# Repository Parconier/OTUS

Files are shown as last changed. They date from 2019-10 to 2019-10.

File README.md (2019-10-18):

# OTUS: 3D Printed Robotics Kit by Parconier 

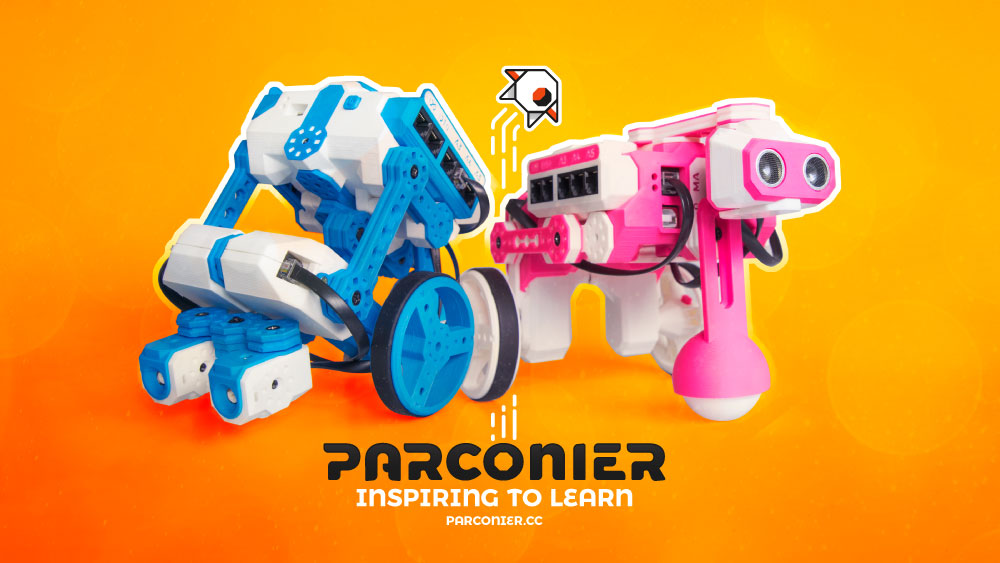
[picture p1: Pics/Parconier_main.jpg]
OTUS


[Click here to purchase one from the Abierto shop](https://www.abierto.cc/shop/#tags=10849|10852 "abierto.cc")

# Files in this repository

.STL - This files are for 3D printing, if you want to edit any of them, feel free to use the .STEP file.
.STEP - This files contains every pattern in a generic 3D format that you can easily edit.

# Name format

name of the piece "\_" suggestion of color of neutral "\_" ammount per kit "\- v" version of the file

Example:
Patternx2\_color\_x6 \-  v1.0

# License

Copyright CERN 2013. 

This documentation describes Open Hardware and is licensed under the CERN OHL v. 1.2. This means that you are free to use, reproduce, sell or modify our designs in any way you see fit, as long as you retain this same license for your projects using our work. For those wanting to use our hardware designs and/or software packages, we require you:

Label the product as a clone. It must be clear that it is not a product from our factory.
Note that "OTUS is a registered trademark of Parconier".
Host your own copy of the source files on your own server or similar, even if they are unmodified. Do not just point to our existing source.

You may redistribute and modify this documentation under the terms of the CERN OHL v.1.2. (http://ohwr.org/cernohl). This documentation is distributed WITHOUT ANY EXPRESS OR IMPLIED WARRANTY, INCLUDING OF MERCHANTABILITY, SATISFACTORY QUALITY AND FITNESS FOR A PARTICULAR PURPOSE. Please see the CERN OHL v.1.2 for applicable conditions.

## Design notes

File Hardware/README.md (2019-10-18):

# PCB files for the OTUS 3D Printed Robotics Kit  

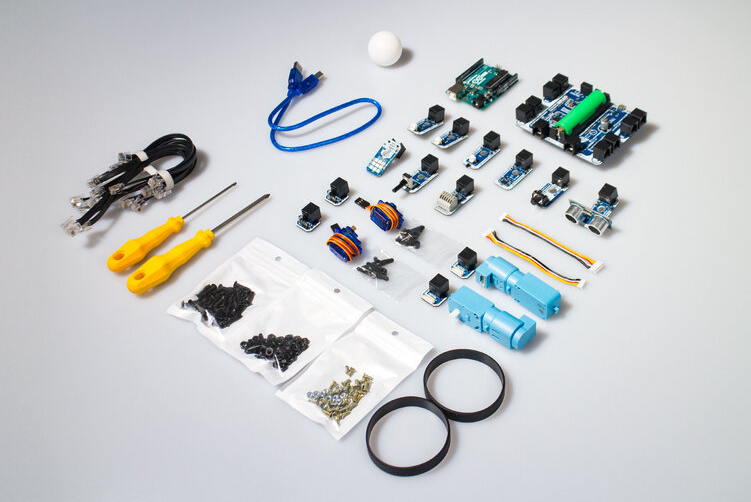
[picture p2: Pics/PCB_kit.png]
OTUS PCB kit


[Click here to purchase OTUS PCB boards from the Abierto shop](https://www.abierto.cc/shop/product/67049/otus-electronica/ "abierto.cc")

 Format is EagleCAD for Schematic and board layout.

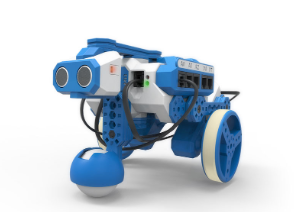
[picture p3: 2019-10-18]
Pics/OTUS.png

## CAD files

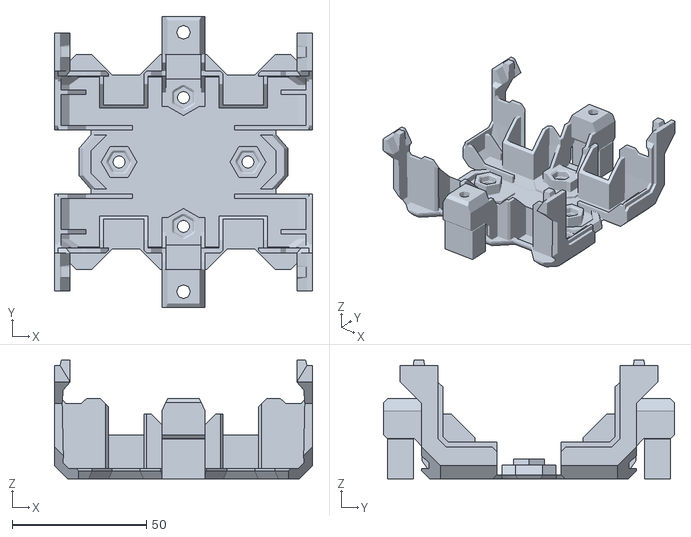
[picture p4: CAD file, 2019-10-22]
Construction System/Enclosures - v0.2/Interface - v0.2/interface_mainA_neutral_x1_v0.2.stl
96.2 x 108.4 x 44.3

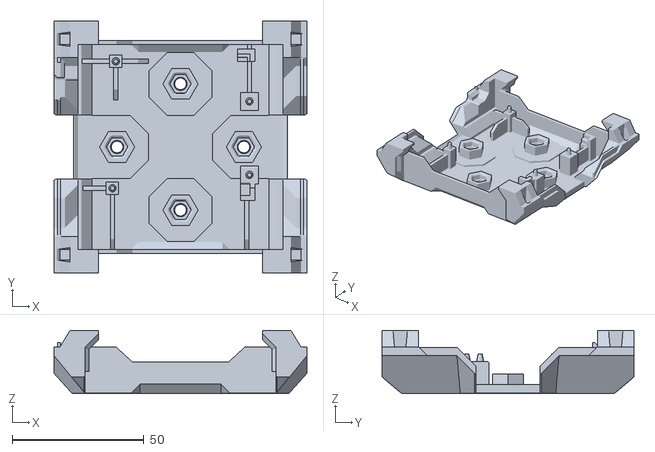
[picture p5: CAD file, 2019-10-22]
Construction System/Enclosures - v0.2/Interface - v0.2/interface_mainB_neutral_x1_v0.2.stl
96.2 x 96.0 x 24.0

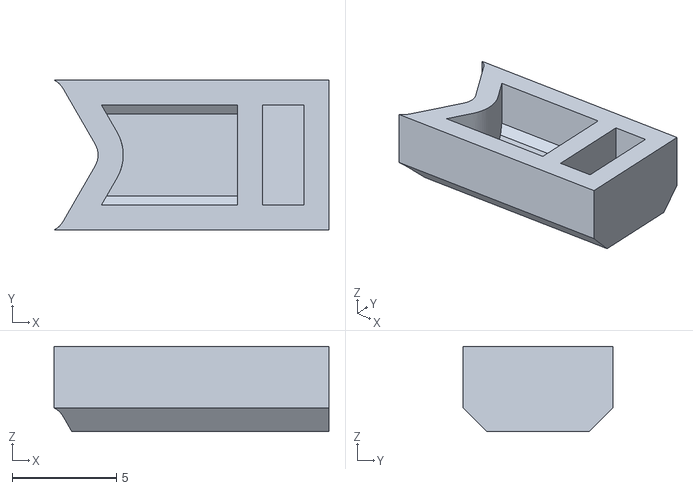
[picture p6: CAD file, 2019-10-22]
Construction System/Enclosures - v0.2/Actuators/Motor - v0.1/wheel_lock_neutral_x2_v0.1.stl
13.2 x 7.20 x 4.10

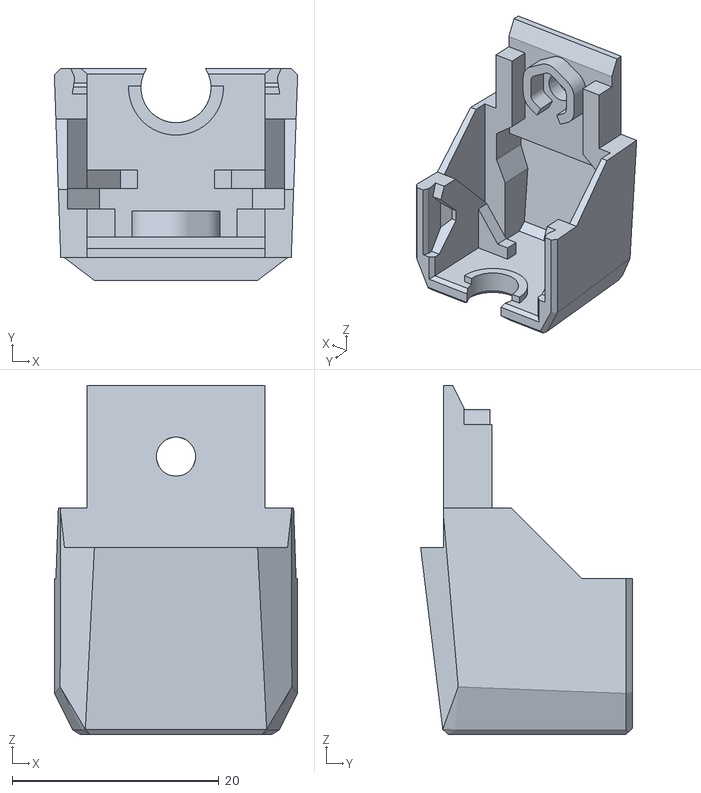
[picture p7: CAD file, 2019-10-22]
Construction System/Enclosures - v0.2/Actuators/Potenciometer - v0.2/pote_female_color_x1_v0.2.stl
23.6 x 20.5 x 33.8

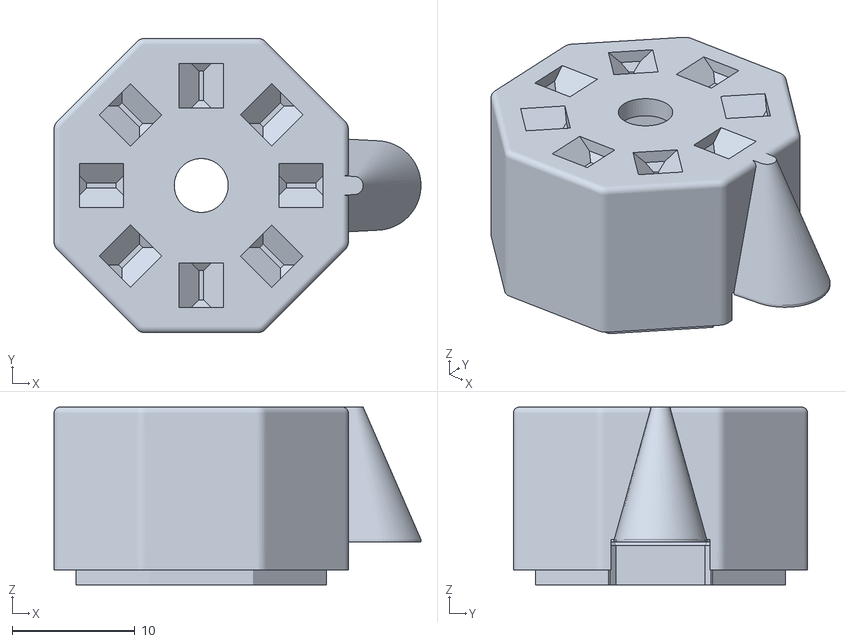
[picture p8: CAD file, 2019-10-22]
Construction System/Enclosures - v0.2/Actuators/Servomotor - v0.1/servo_headB_neutral_x2_v0.1.stl
29.9 x 24.0 x 14.5

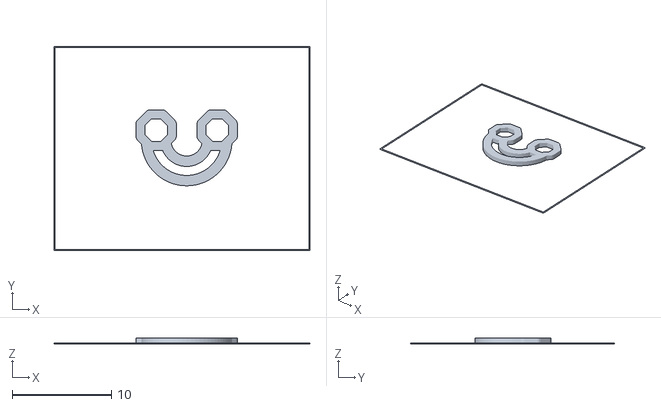
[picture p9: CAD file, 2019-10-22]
Construction System/Enclosures - v0.2/Others/Adapter - v0.2/adapter_female_neutral_x1_v0.2.stl
25.8 x 20.5 x 0.6

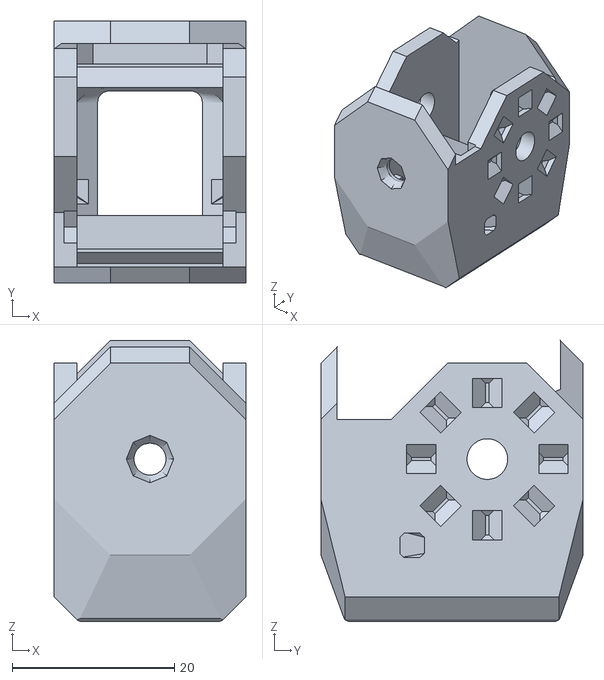
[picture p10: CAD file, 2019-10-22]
Construction System/Enclosures - v0.2/Sensors/Button_Sensor - v0.2/button_closure_neutral_x1_v0.2.stl
23.6 x 32.3 x 34.6

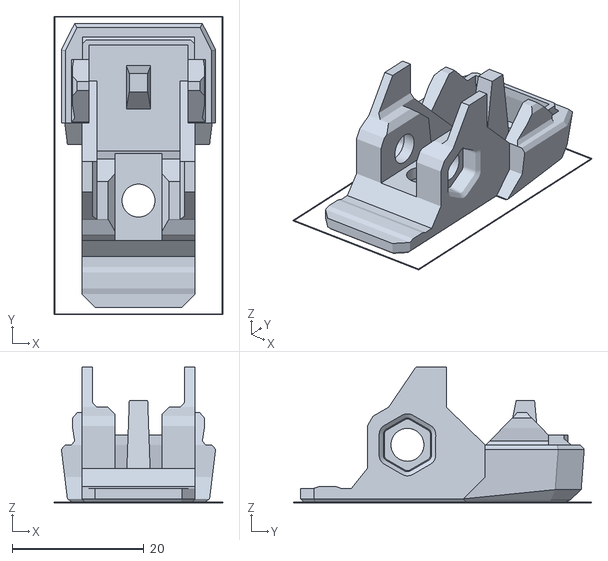
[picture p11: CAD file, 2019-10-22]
Construction System/Enclosures - v0.2/Sensors/Contrast_Sensor - v0.2/contrast_male_color_x2_v0.2.stl
25.6 x 45.3 x 20.6

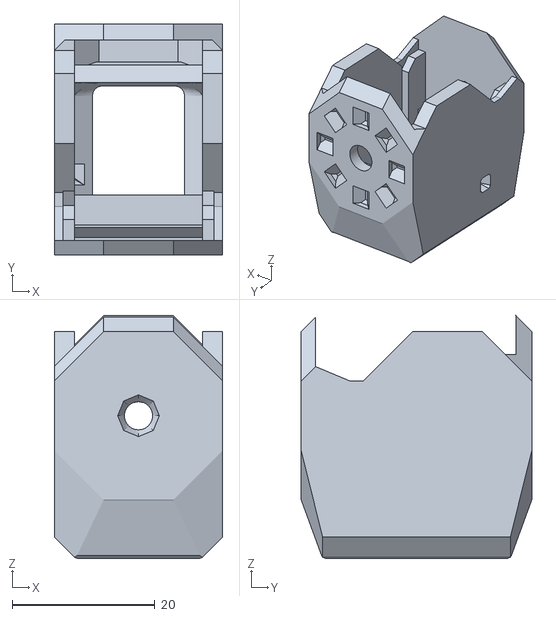
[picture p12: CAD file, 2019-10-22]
Construction System/Enclosures - v0.2/Sensors/Distance_Sensor - v0.2/distance_closure_neutral_x1_v0.2.stl
23.6 x 32.3 x 34.0

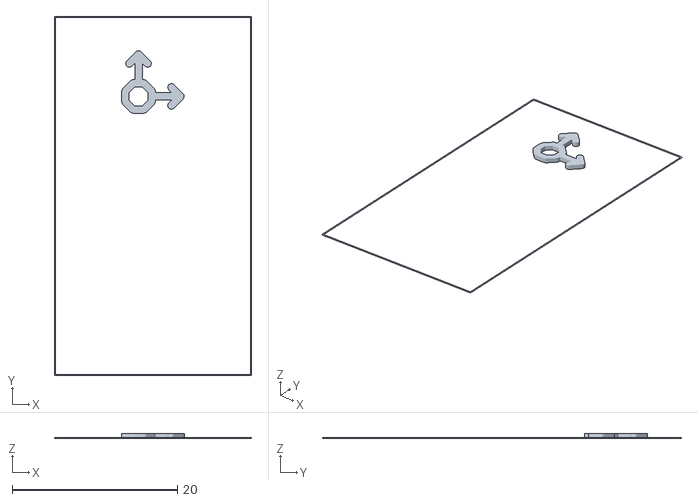
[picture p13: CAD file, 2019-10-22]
Construction System/Enclosures - v0.2/Sensors/IMU_Sensor - v0.2/IMU_male_neutral_x1_v0.2.stl
23.8 x 43.5 x 0.6

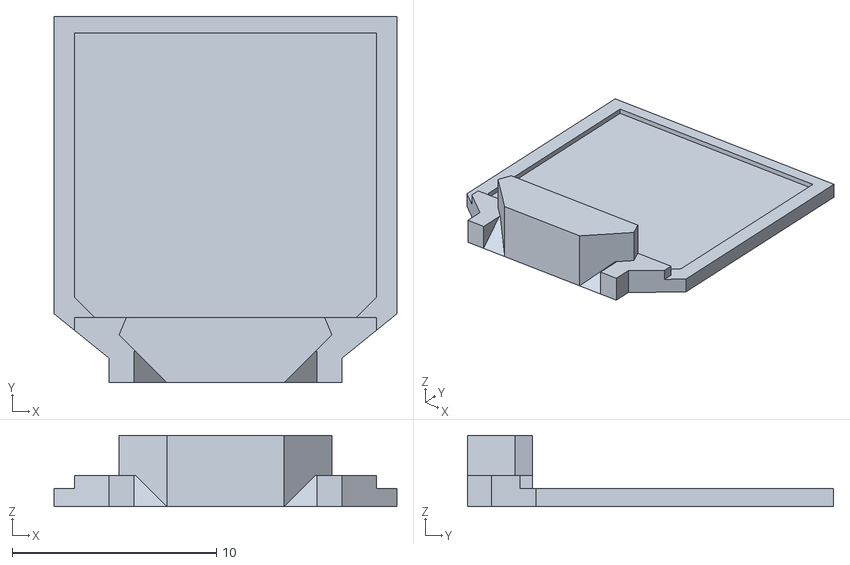
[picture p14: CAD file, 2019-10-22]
Construction System/Enclosures - v0.2/Sensors/LED_Matrix_3x3 - v0.2/LEDM3x3_cover_neutral_x1_v0.2.stl
16.8 x 17.9 x 3.49

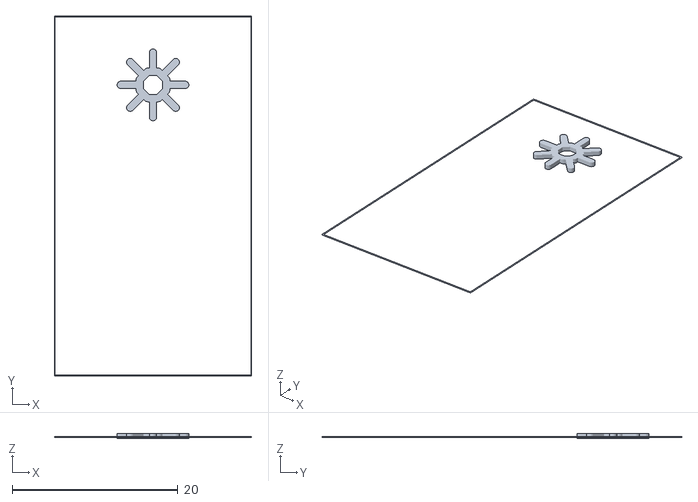
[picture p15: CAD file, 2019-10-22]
Construction System/Enclosures - v0.2/Sensors/Light_Sensor - v0.2/light_male_neutral_x1_v0.2.stl
23.8 x 43.5 x 0.6

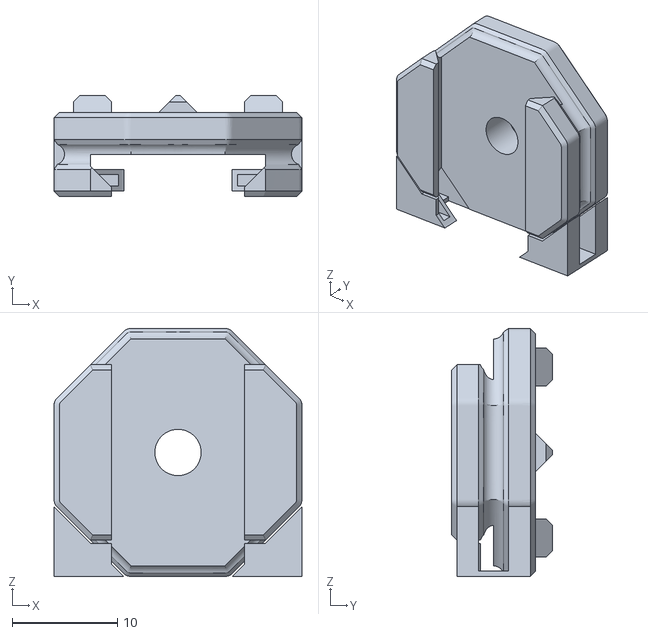
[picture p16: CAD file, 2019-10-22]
Construction System/Others - v0.2/Omni_wheel - v0.2/Omni_wheel_slider_neutral_x1_v02.stl
23.6 x 9.60 x 23.6

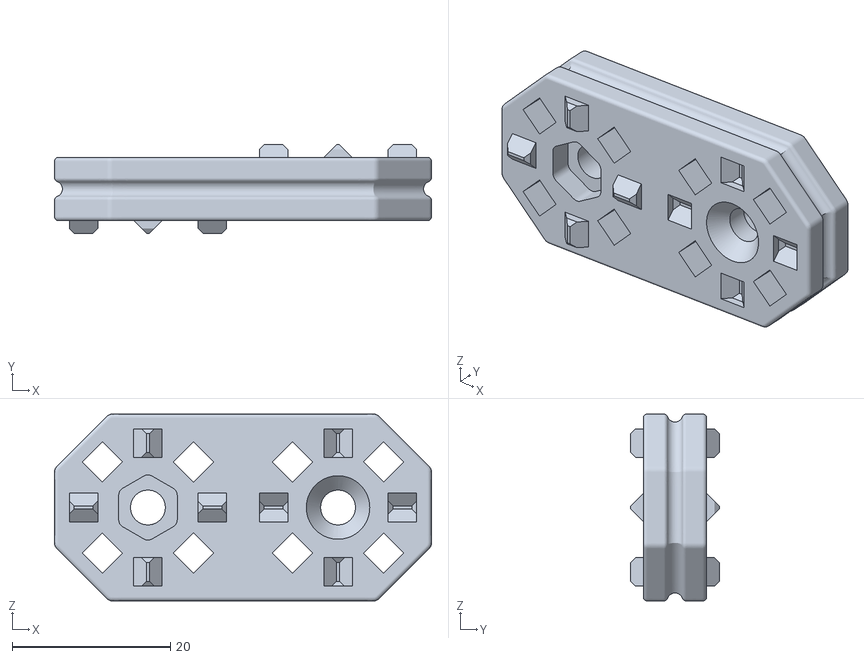
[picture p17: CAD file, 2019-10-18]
Construction System/Patterns - v0.2/Inversor_color_x3 - v0.2.stl
47.6 x 11.2 x 23.6

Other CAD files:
Construction System/Enclosures - v0.2/Actuators/Motor - v0.1/motor_closure1p_color_x2_v0.1.stl
Construction System/Enclosures - v0.2/Actuators/Potenciometer - v0.2/pote_knob_neutral_x1_v0.2.stl
Construction System/Enclosures - v0.2/Actuators/Servomotor - v0.1/servo_closure_neutral_x2_v0.1.stl
Construction System/Enclosures - v0.2/Interface - v0.2/interface_onoff_neutral_x1_v0.2.stl
Construction System/Enclosures - v0.2/Actuators/Motor - v0.1/motor_axis_color_x2_v0.1.stl
Construction System/Enclosures - v0.2/Actuators/Motor - v0.1/motor_closure2p_color_x2_v0.1.stl
Construction System/Enclosures - v0.2/Actuators/Motor - v0.1/motor_female_neutral_x2_v0.1.stl
Construction System/Enclosures - v0.2/Actuators/Motor - v0.1/motor_male_neutral_x2_v0.1.stl
Construction System/Enclosures - v0.2/Actuators/Motor - v0.1/wheel_color_x2_v0.1.stl
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

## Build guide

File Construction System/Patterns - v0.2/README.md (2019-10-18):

## Introduction

Here you will find all the different patterns that you can use or print.
The base pattern is a 24 mm octagon, pretty much everything derives from it, so if you would like to design something, this is the fundamental piece.

## Files
.STL - This files are for 3D printing the, if you want to edit any of them, feel free to use the .STEP file.
.STEP - This files contains every pattern in a generic 3D format that you can easily edit.

## Name format
name of the piece "\_" suggestion of color of neutral "\_" ammount per kit "\- v" version of the file

## Example:
Patternx2_color_x6 -  v1.0

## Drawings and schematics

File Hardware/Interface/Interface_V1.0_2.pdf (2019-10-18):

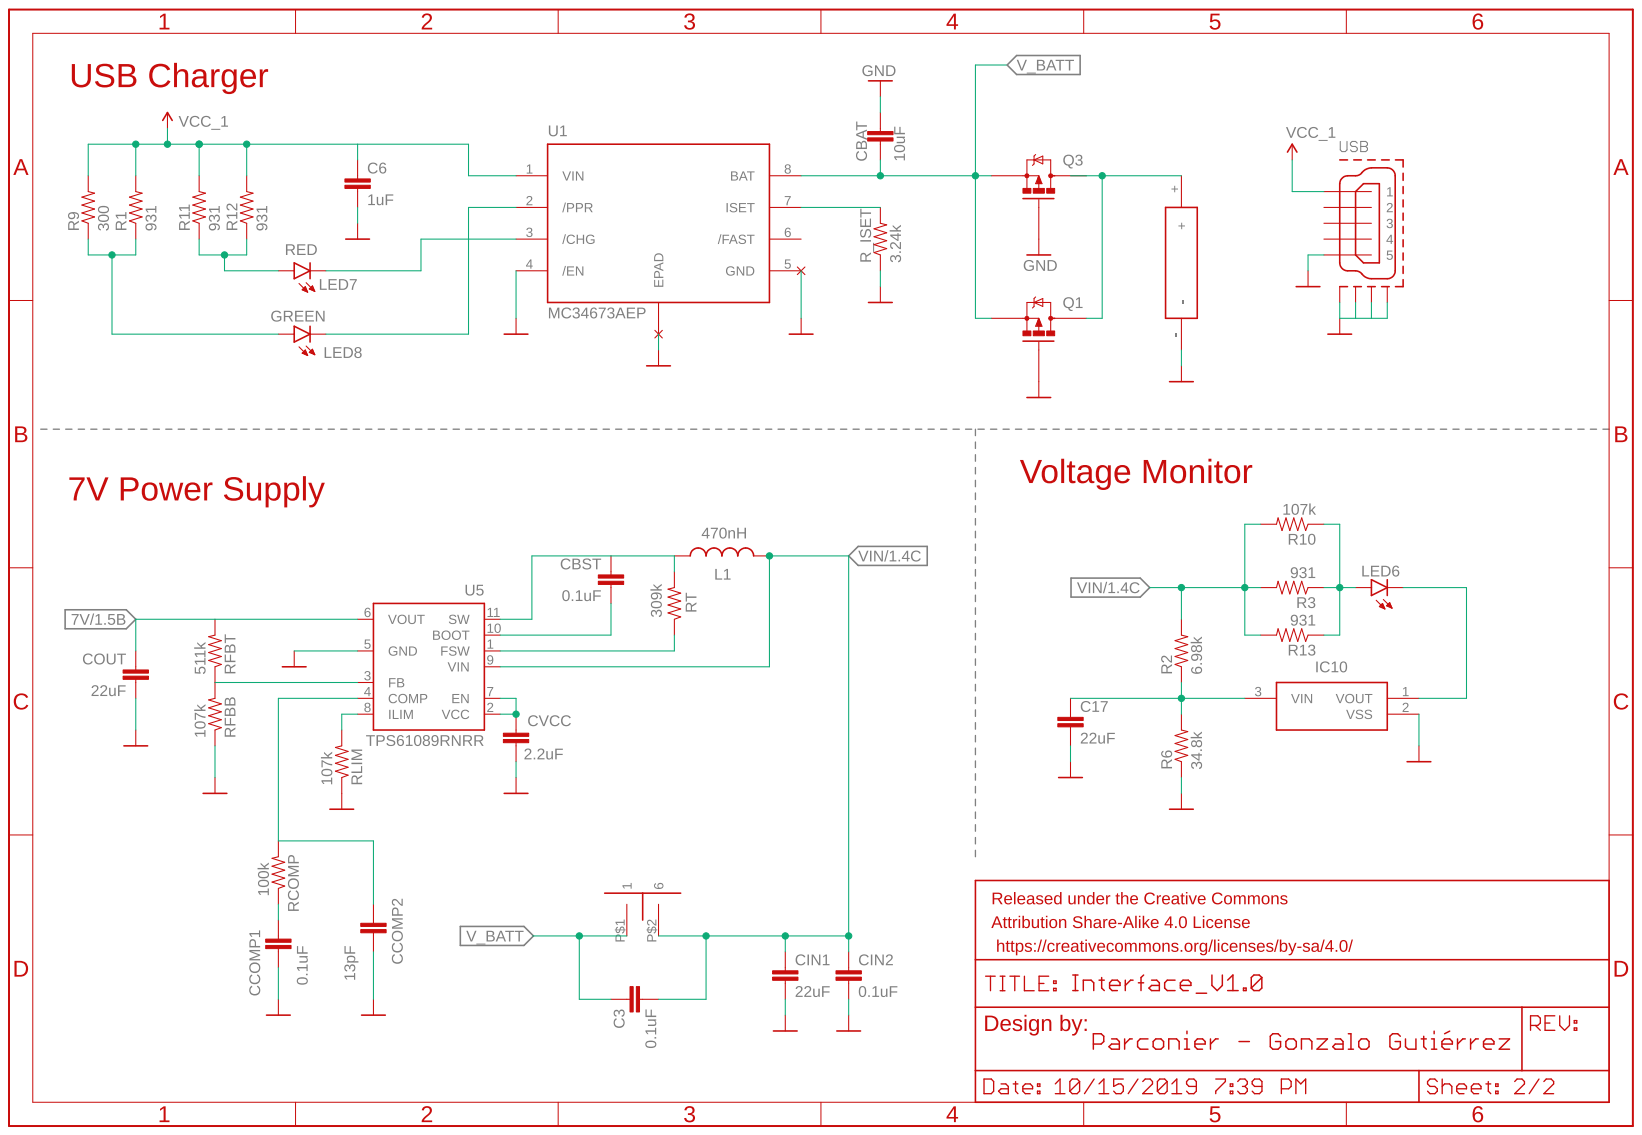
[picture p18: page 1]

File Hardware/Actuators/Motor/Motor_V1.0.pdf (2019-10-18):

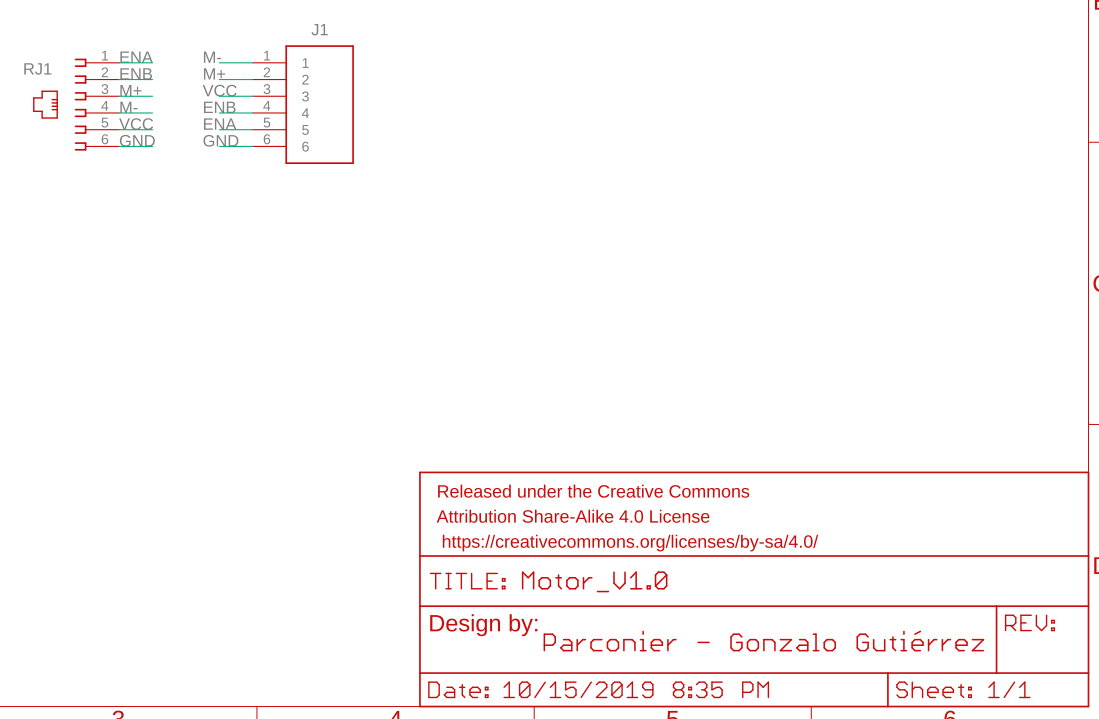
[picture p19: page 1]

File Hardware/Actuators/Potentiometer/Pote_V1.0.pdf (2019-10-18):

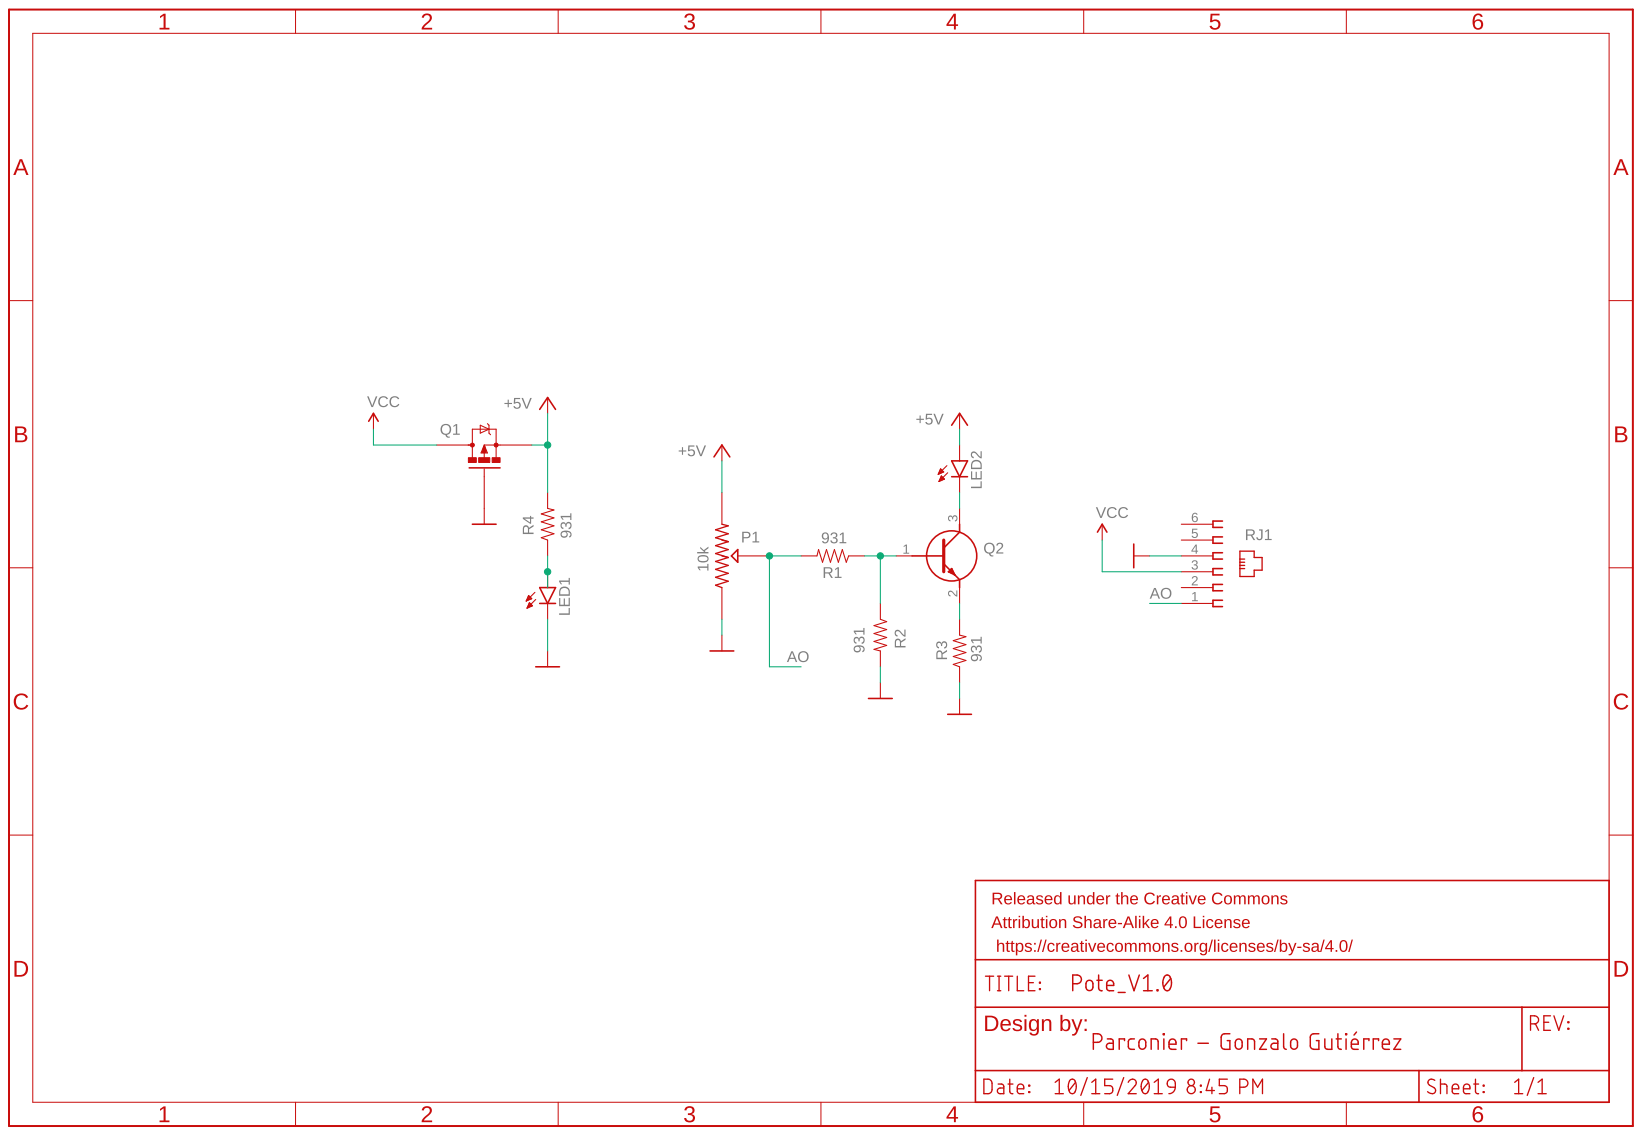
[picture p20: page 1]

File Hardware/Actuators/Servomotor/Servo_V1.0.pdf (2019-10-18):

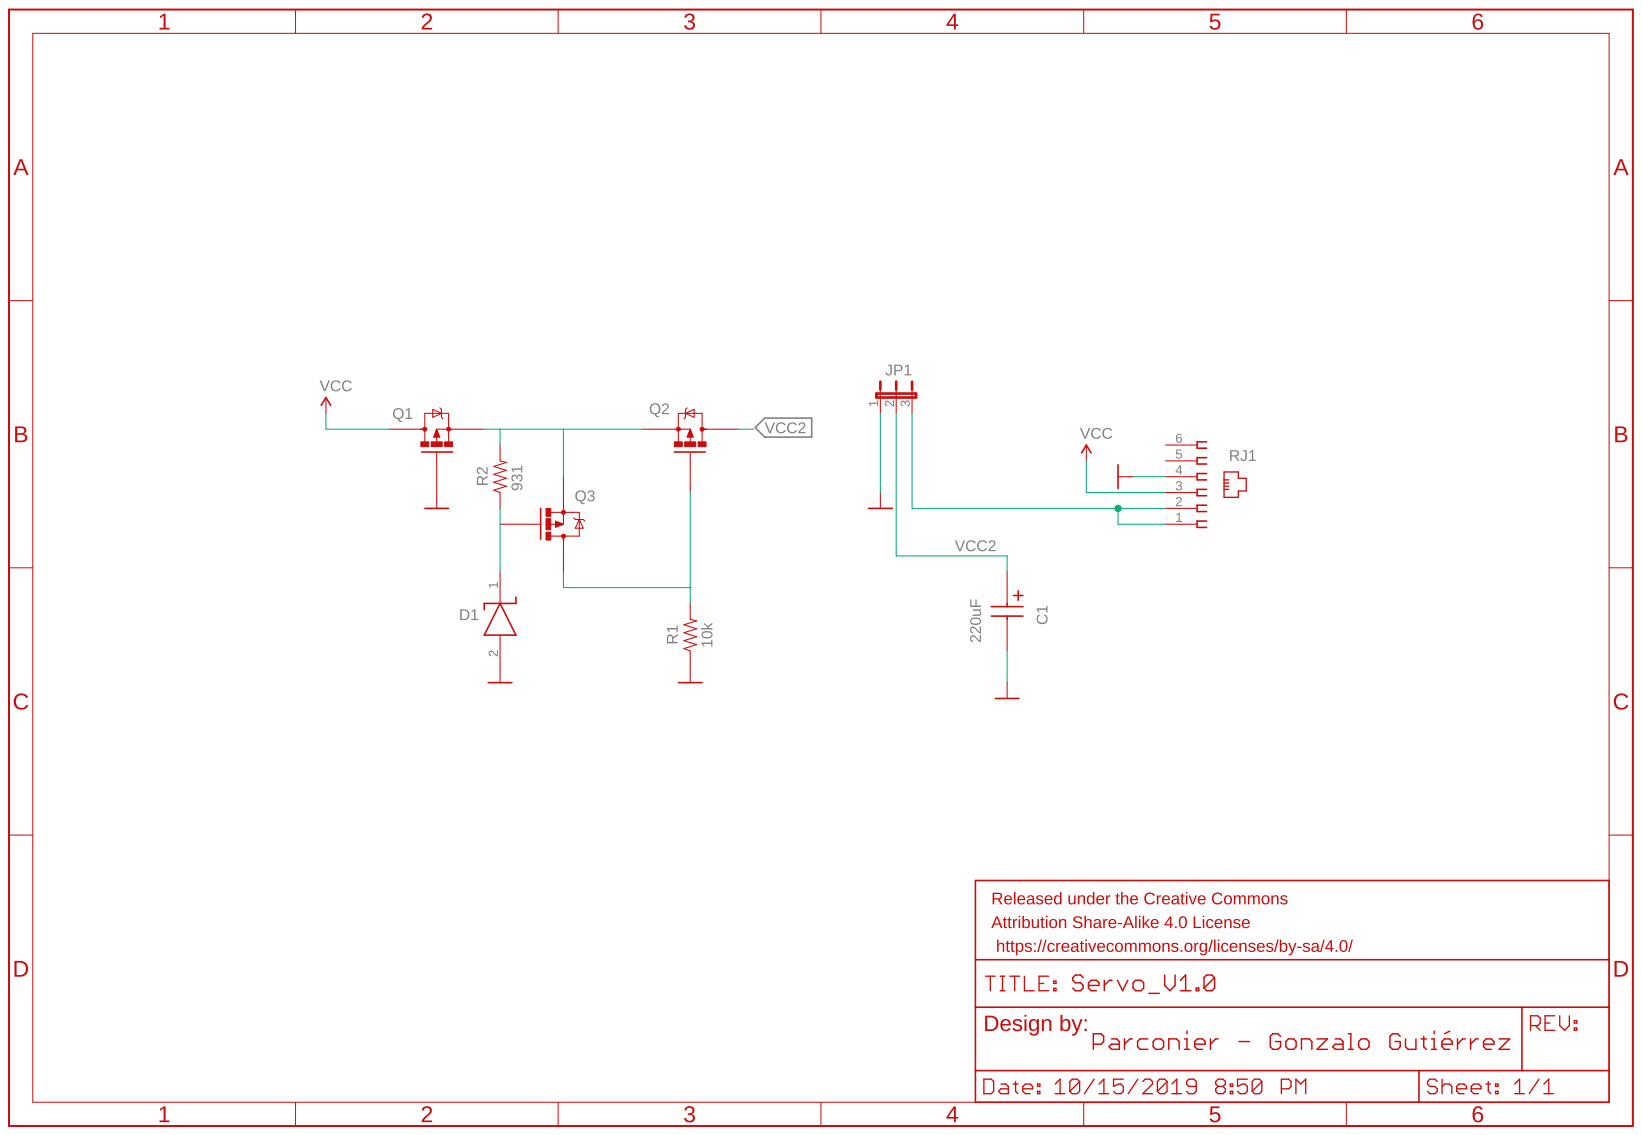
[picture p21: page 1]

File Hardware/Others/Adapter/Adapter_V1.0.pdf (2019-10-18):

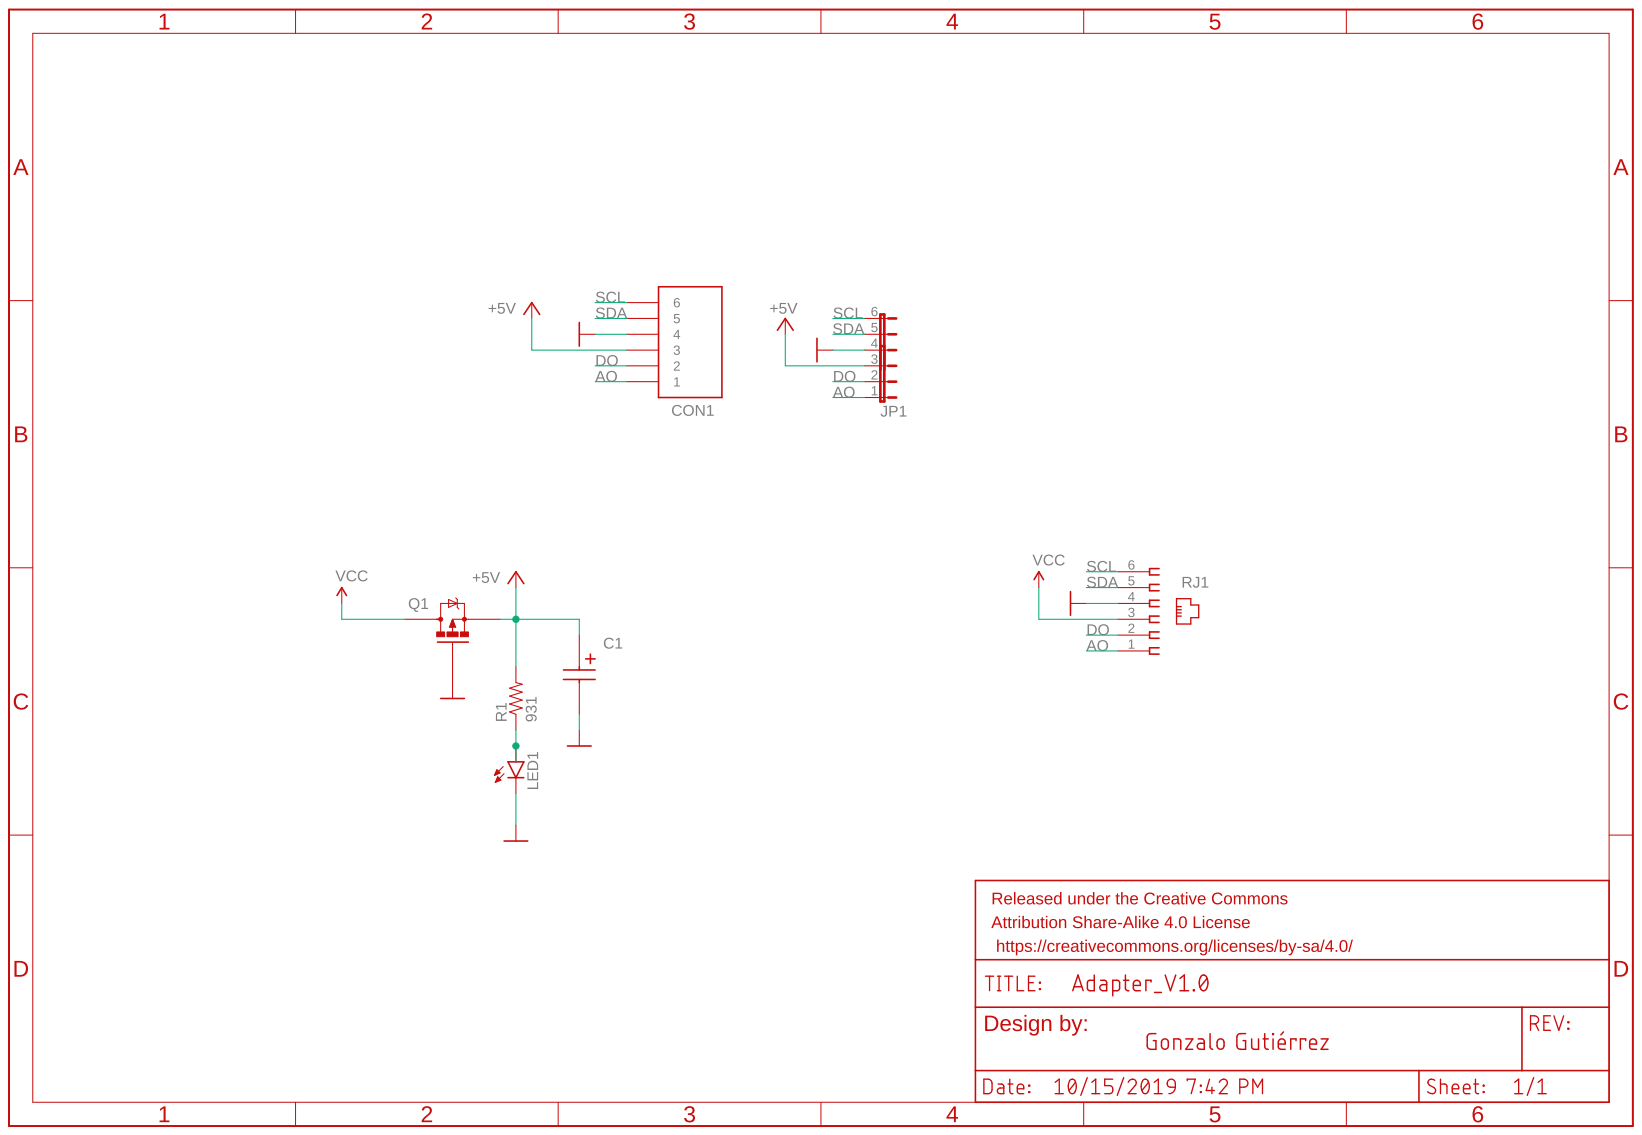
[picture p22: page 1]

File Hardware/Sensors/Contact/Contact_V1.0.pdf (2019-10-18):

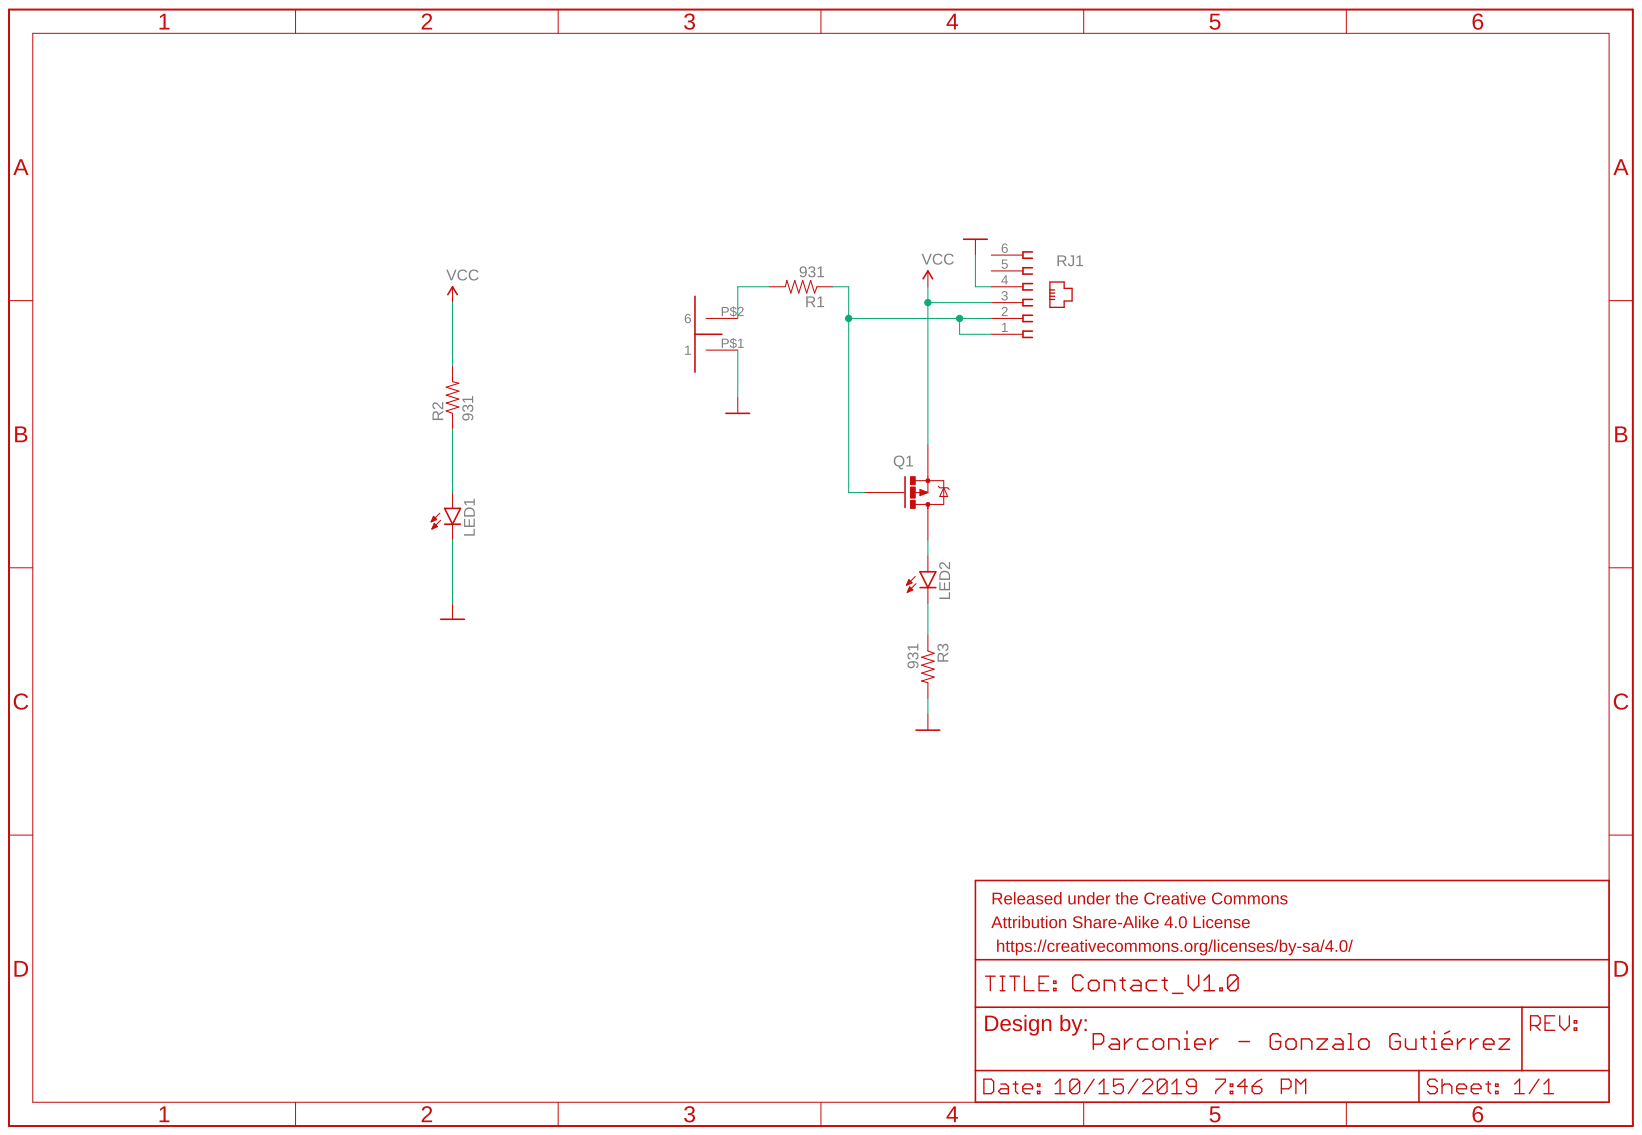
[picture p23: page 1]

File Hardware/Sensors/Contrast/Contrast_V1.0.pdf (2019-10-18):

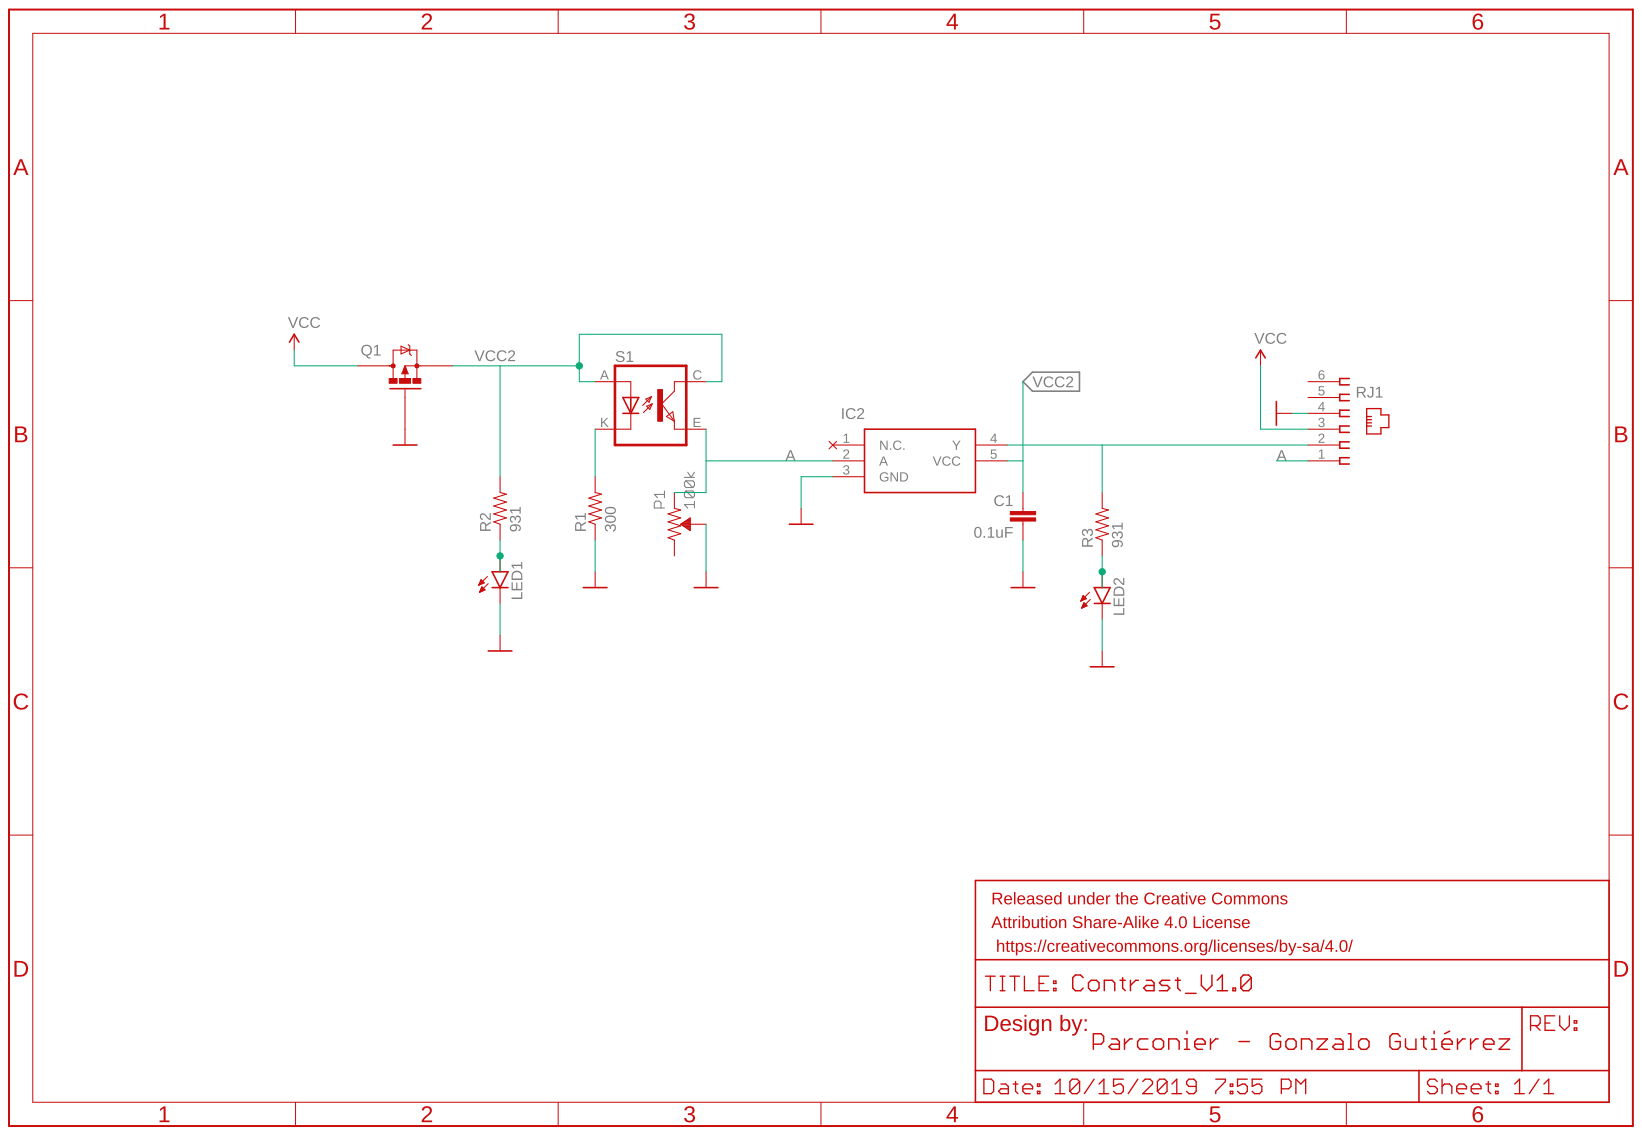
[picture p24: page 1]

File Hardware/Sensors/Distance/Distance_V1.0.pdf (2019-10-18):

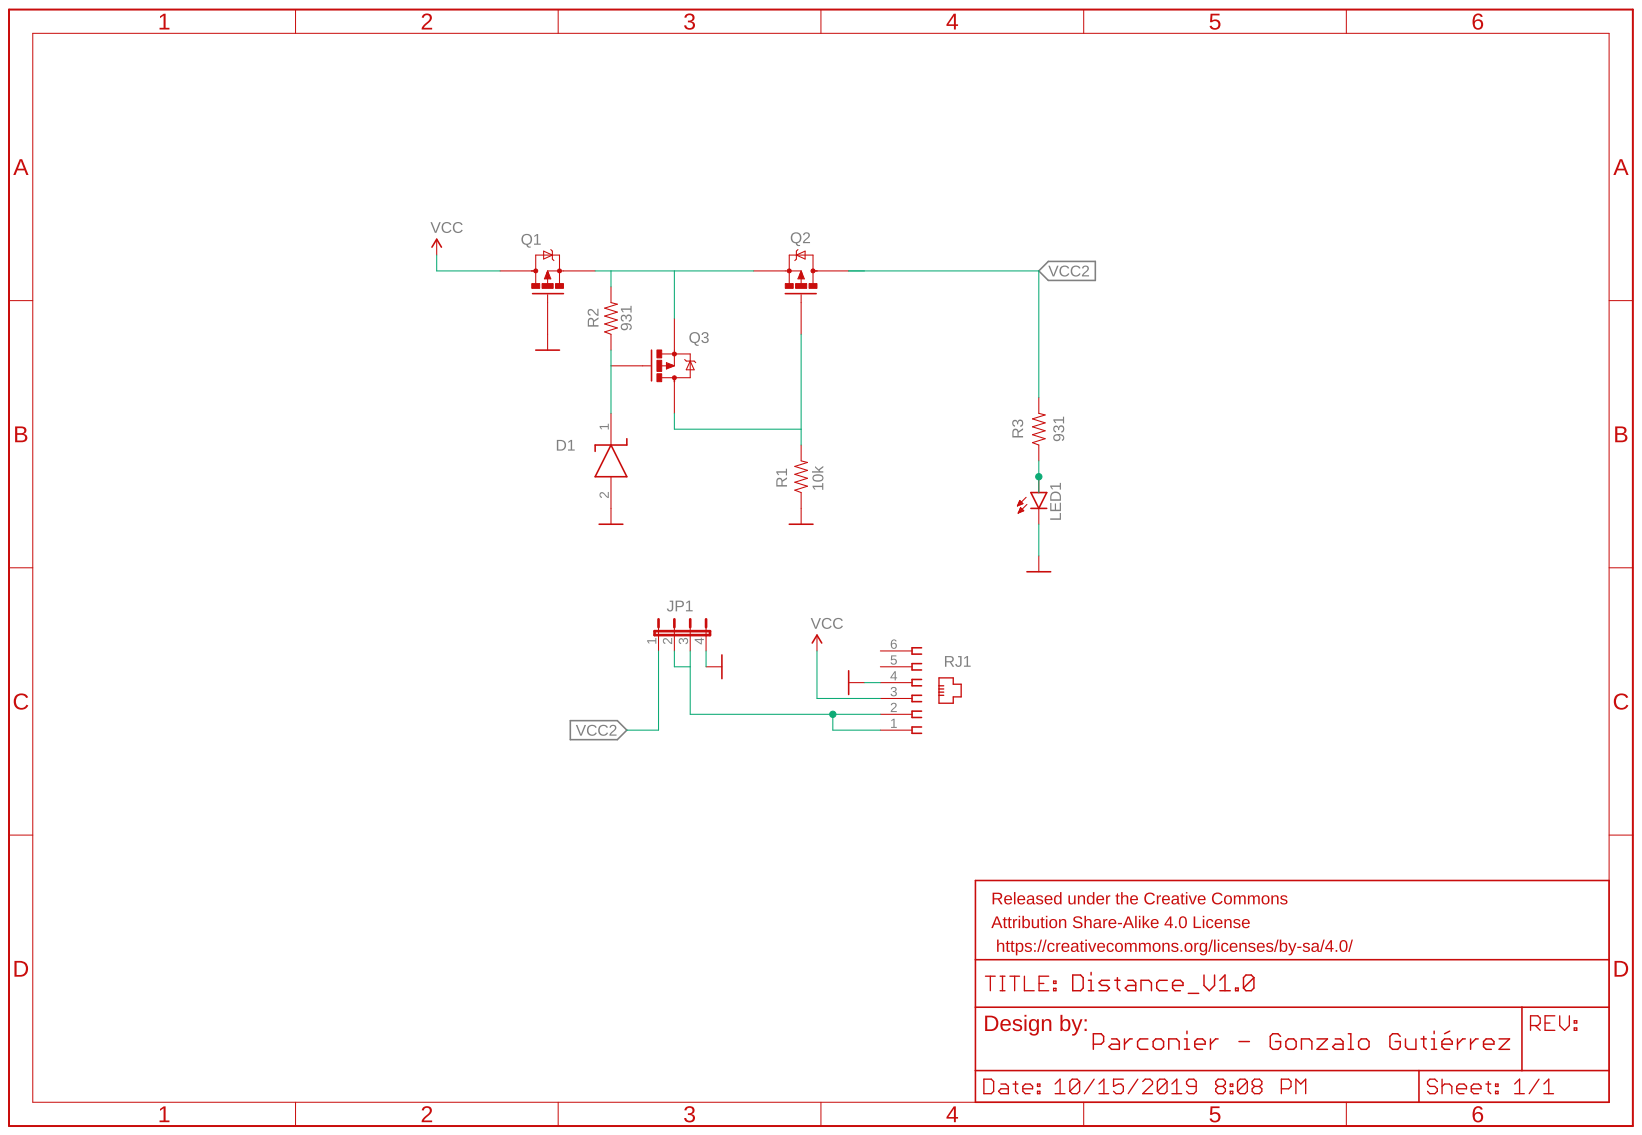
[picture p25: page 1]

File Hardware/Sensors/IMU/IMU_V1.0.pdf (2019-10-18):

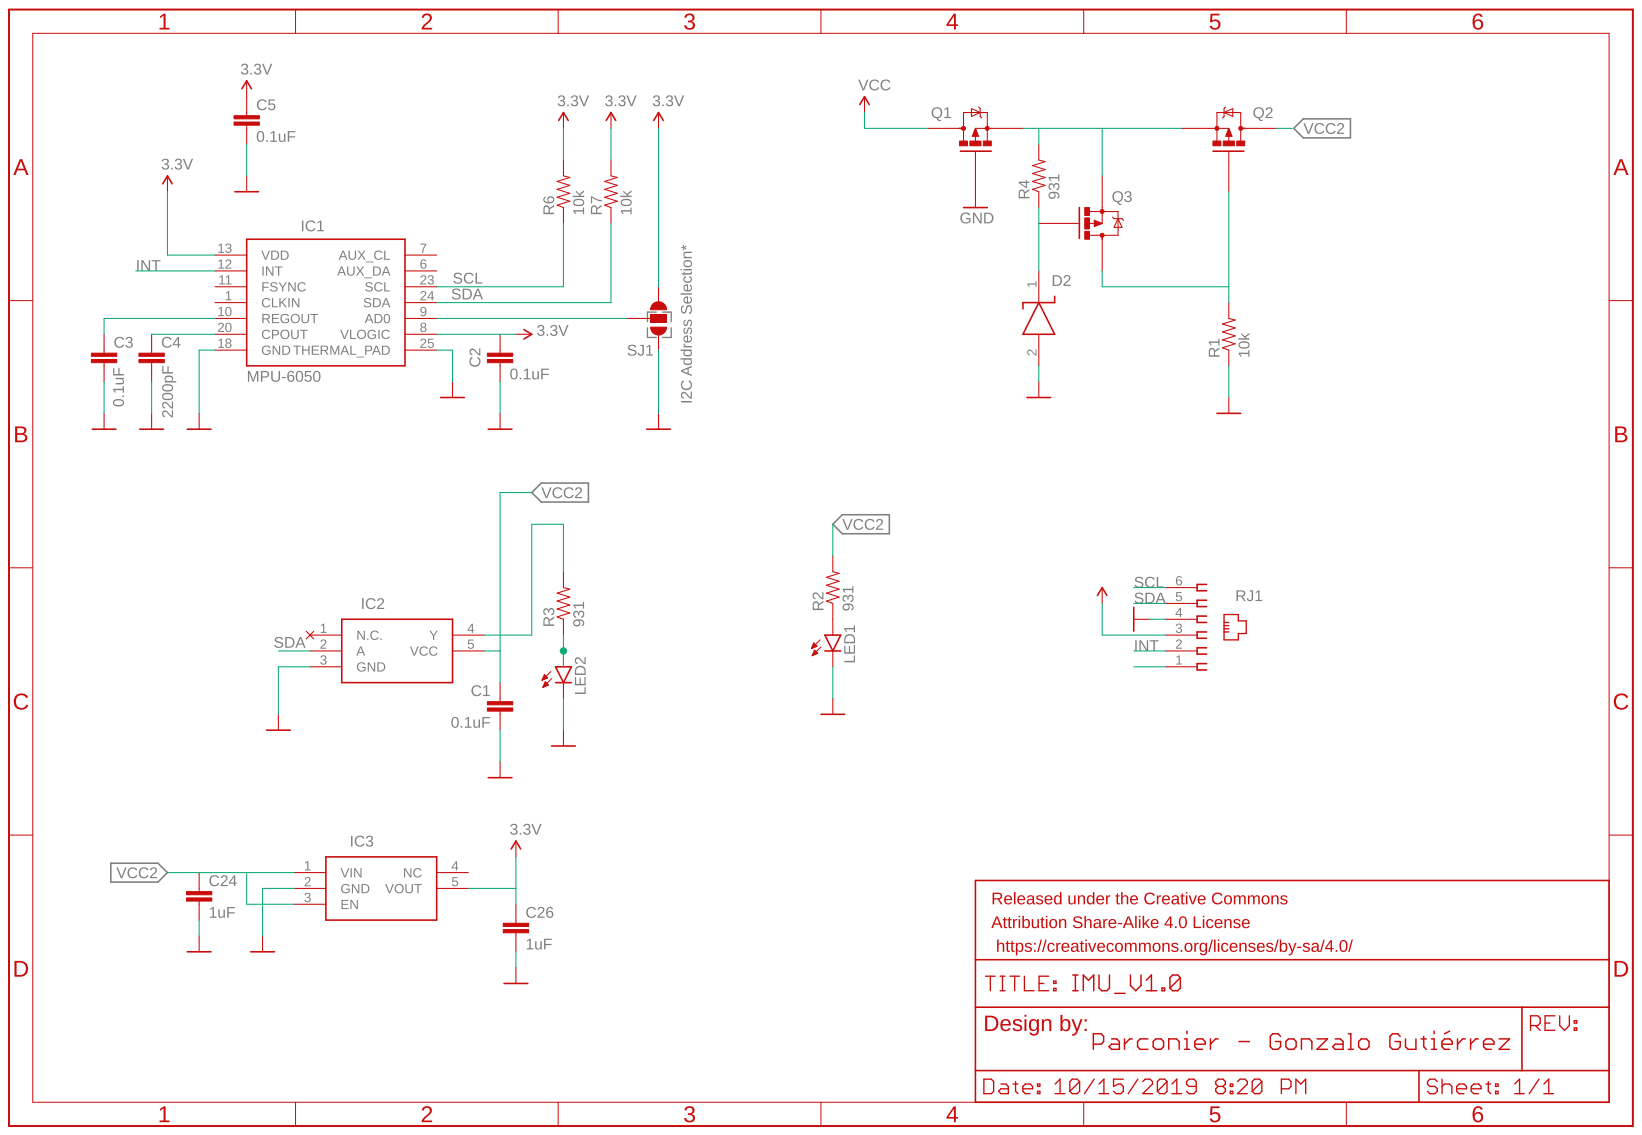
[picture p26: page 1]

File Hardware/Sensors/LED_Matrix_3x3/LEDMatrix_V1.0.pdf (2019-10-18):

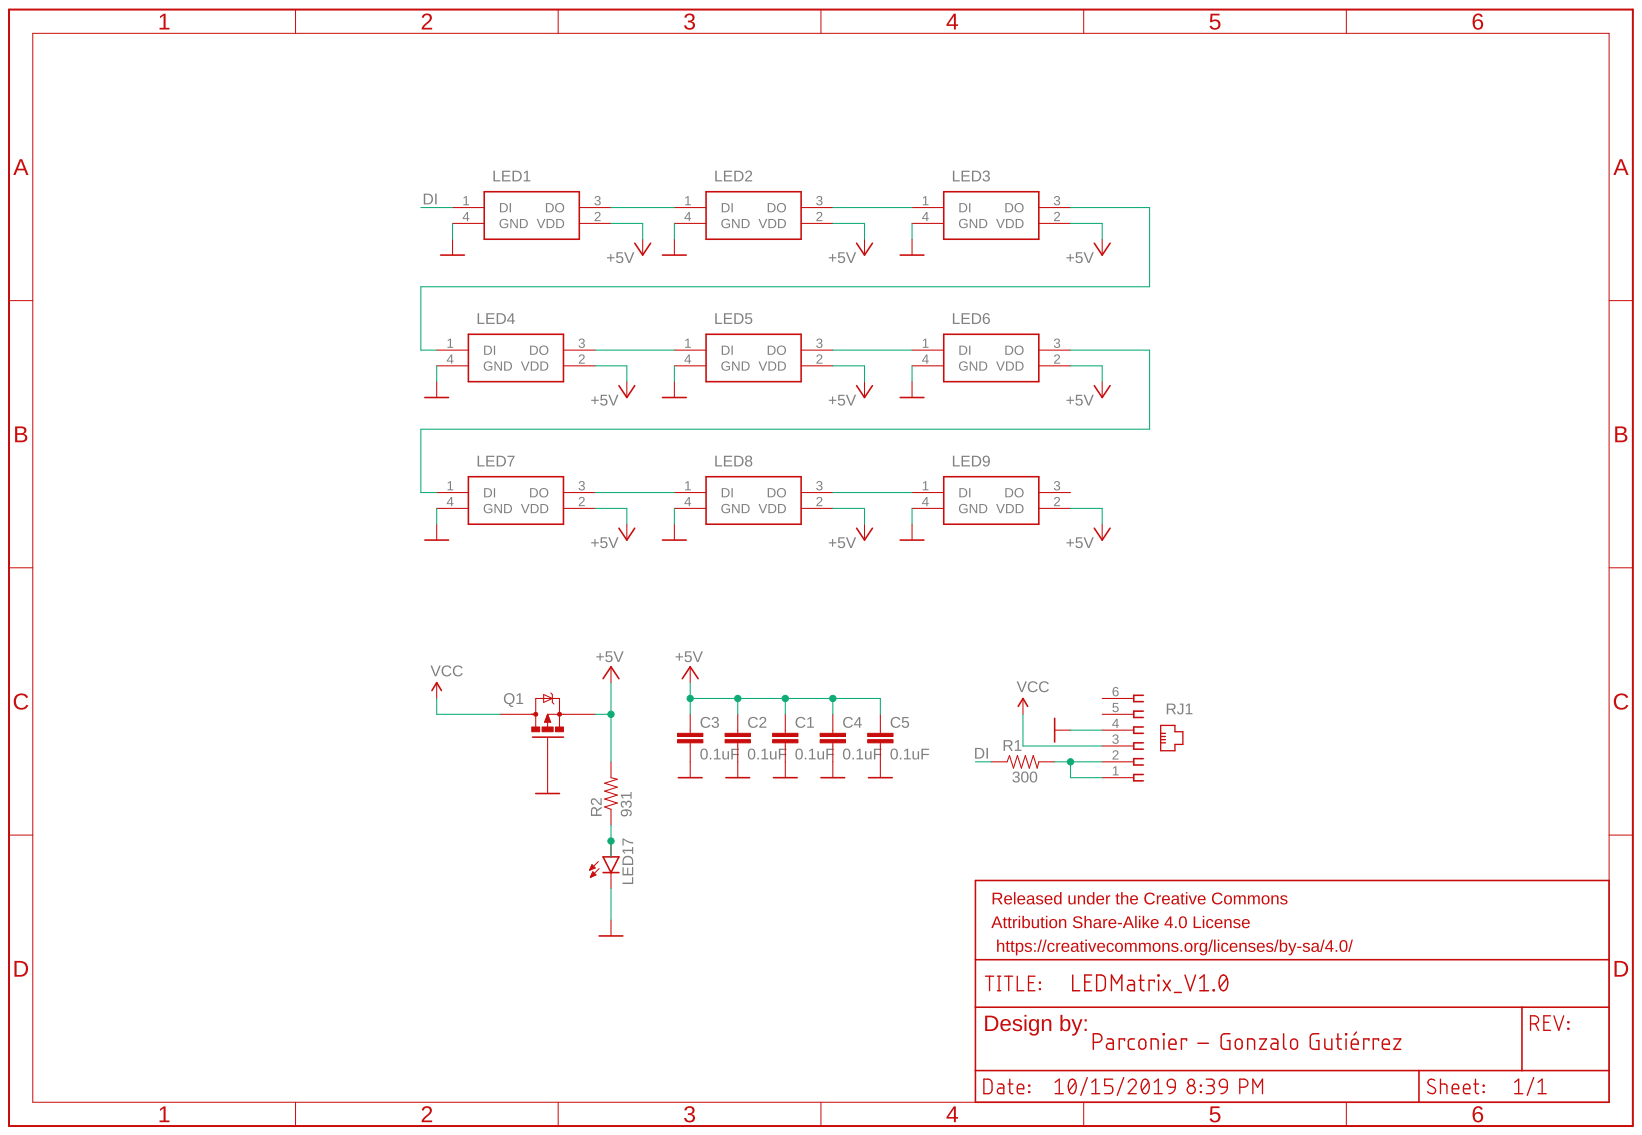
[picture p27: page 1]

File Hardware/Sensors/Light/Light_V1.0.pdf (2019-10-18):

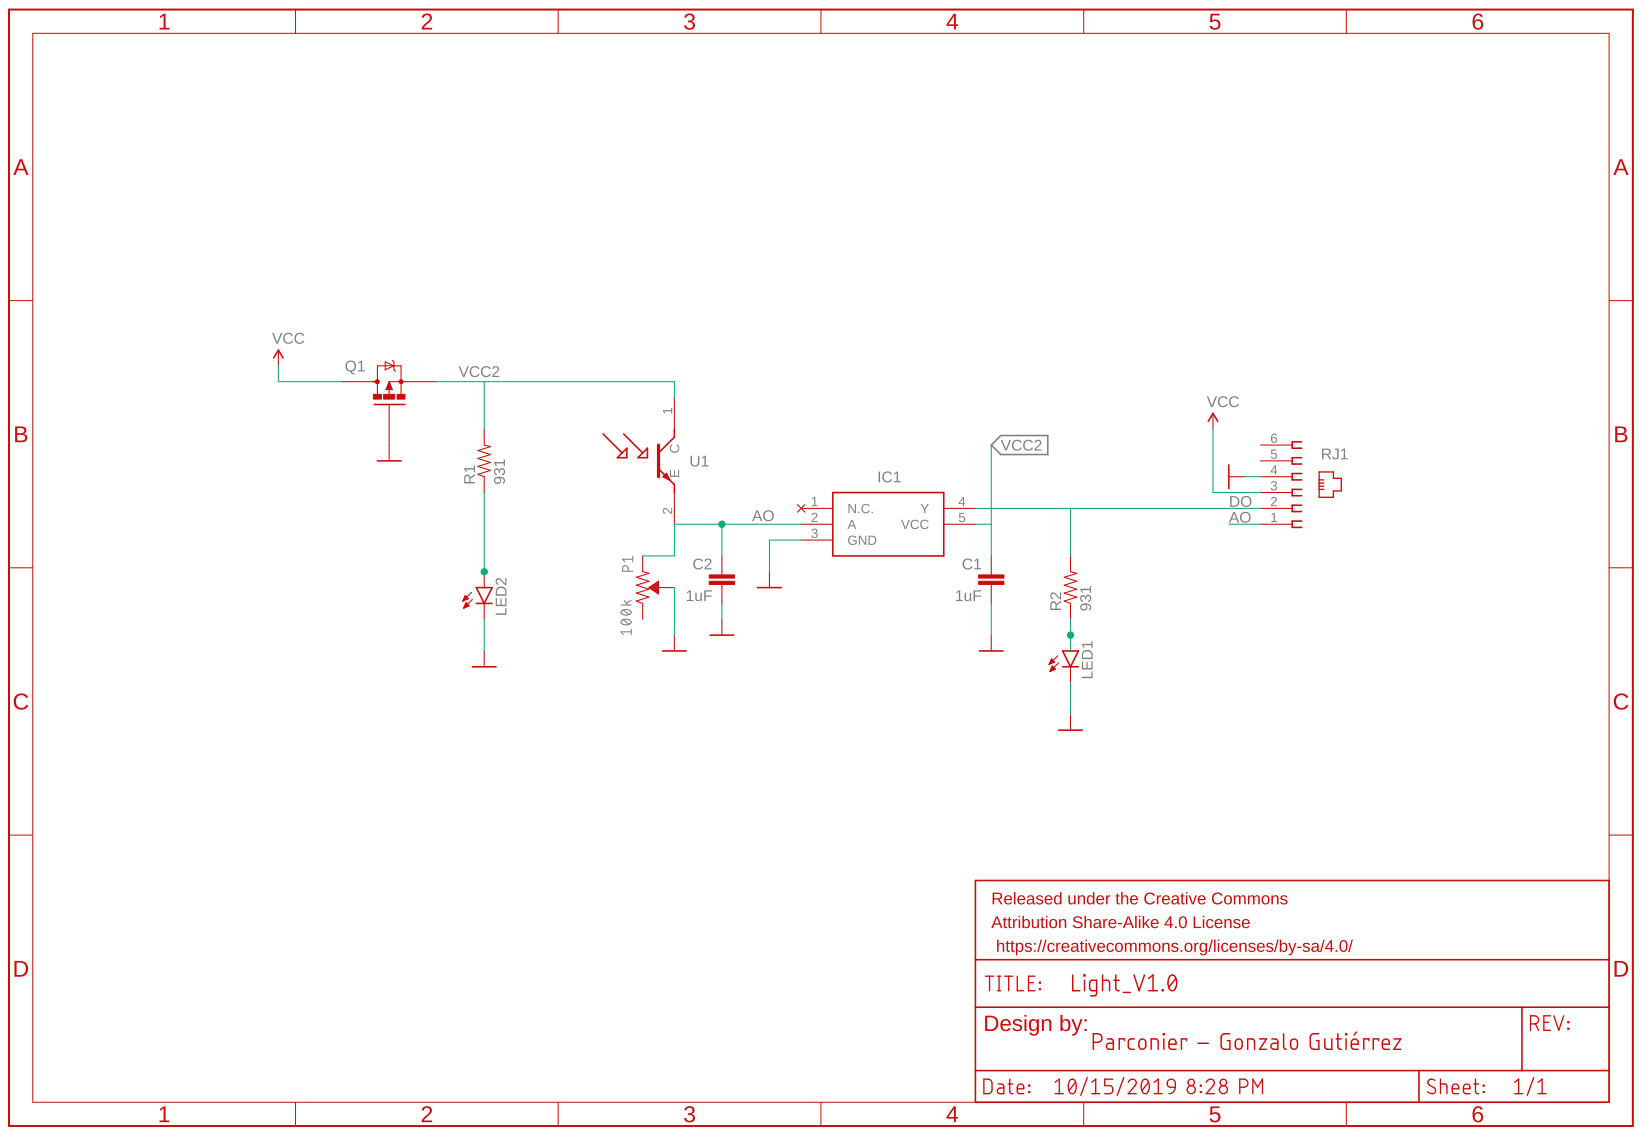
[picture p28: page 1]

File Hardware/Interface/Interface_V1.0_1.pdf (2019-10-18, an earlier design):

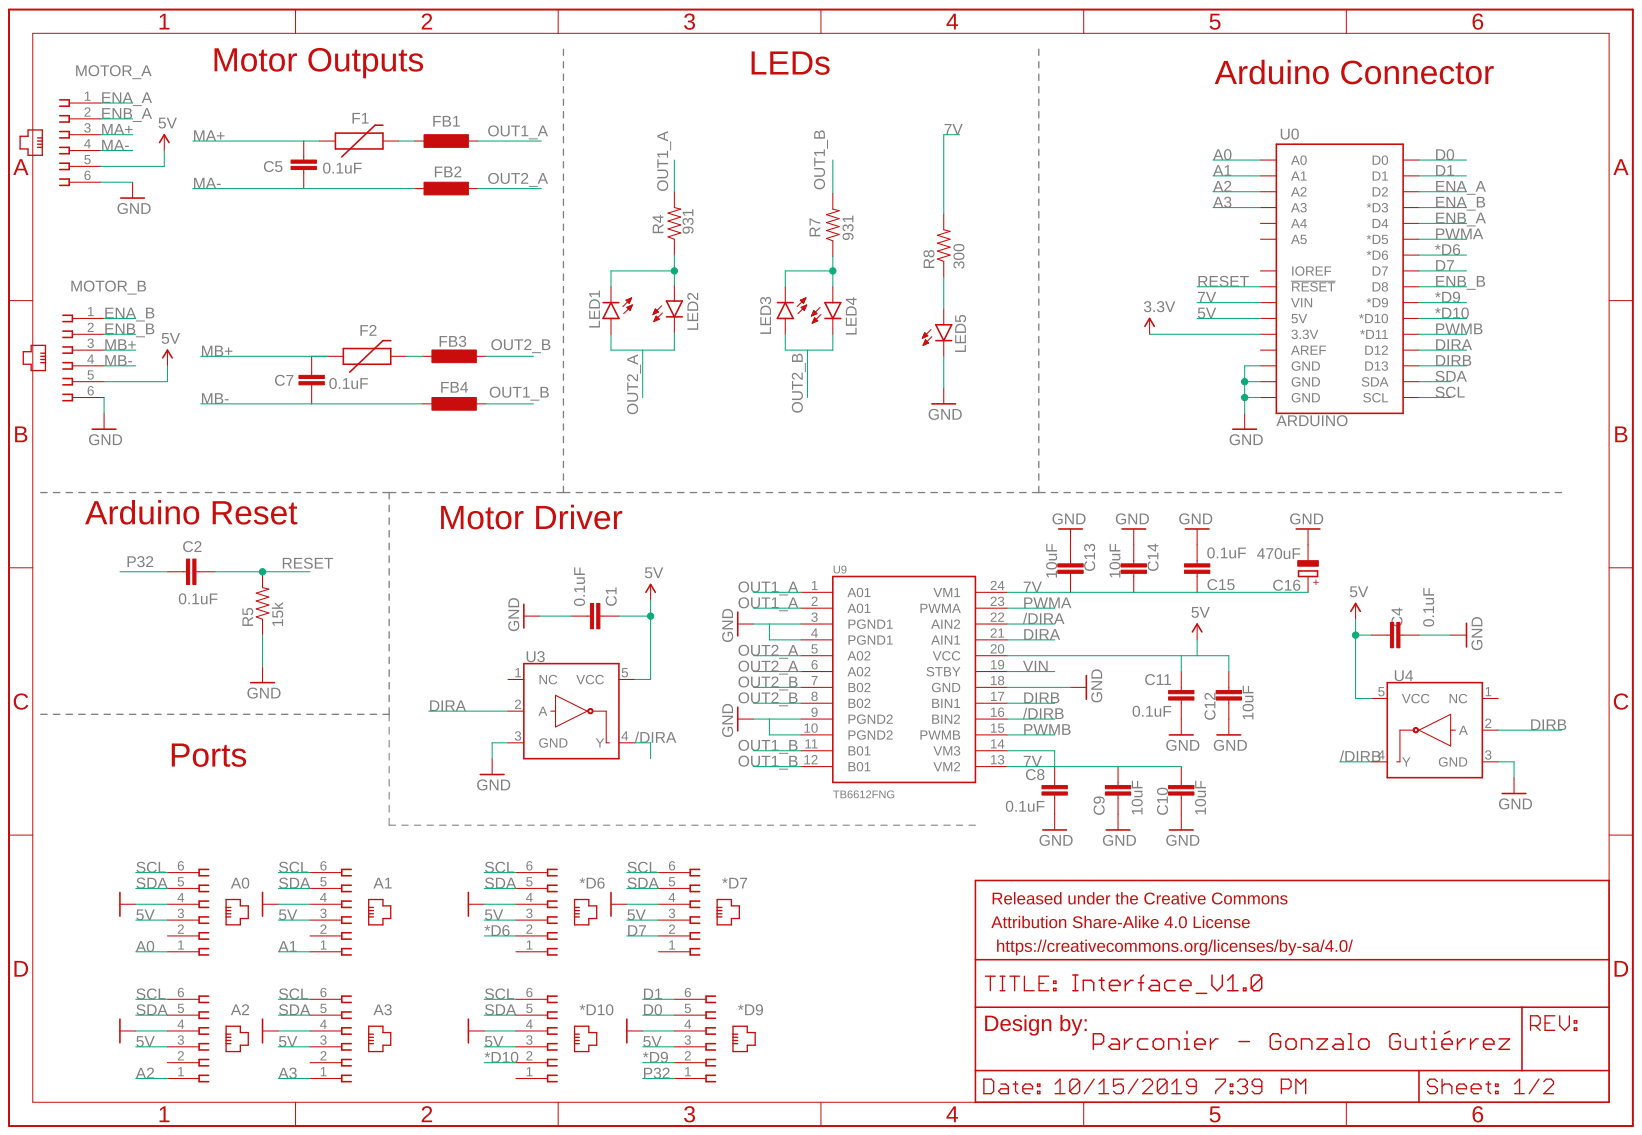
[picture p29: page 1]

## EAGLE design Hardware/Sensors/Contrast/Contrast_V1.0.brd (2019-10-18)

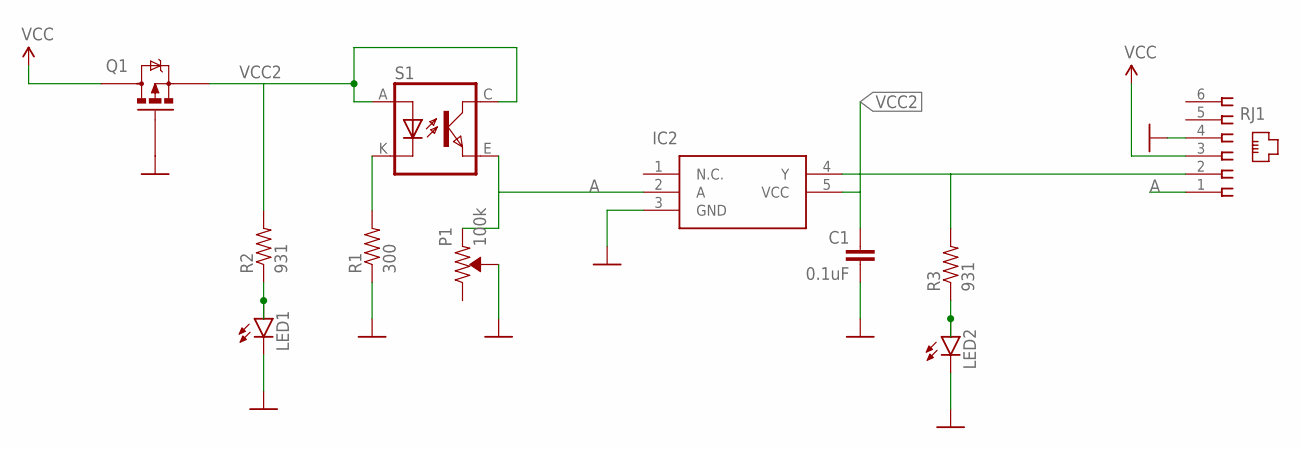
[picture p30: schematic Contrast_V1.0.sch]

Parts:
C1: 0.1uF; 0402; MPN CC0402KRX5R9BB104
IC2: 74LVC1G14GW-Q100,1; SOT65P212X110-5N; MPN 74AHC1G14GW-Q100,1
LED1: LED0603; LED-0603; MPN LTST-C193KRKT-5A
LED2: LED0603; LED-0603; MPN LB Q39E-L2OO-35-1
P1: 100k; 3309W-1-104; MPN 3309W-1-104
Q1: RU1C002ZPTCL; SOTFL65P210X105-3N; MPN RU1C002ZPTCL
R1: 300; RESC1005X35; MPN RC0402JR-07300RL
R2, R3: 931; RESC1005X35; MPN RC0402FR-07931RL
RJ1: 615006138421; MPN 54601-906WPLF
S1: TCRT5000; MPN TCRT5000

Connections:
A: IC2.2 (A), P1.1 (CCW), RJ1.1, S1.E (EMITTER)
GND: C1.2, IC2.3 (GND), LED1.C, LED2.C, P1.2 (WIPER), Q1.1 (G), R1.1, RJ1.4
unnamed: R1.2, S1.K (CATHODE)
unnamed: IC2.4 (Y), R3.2, RJ1.2
unnamed: LED2.A, R3.1
unnamed: LED1.A, R2.1
VCC: Q1.3 (D), RJ1.3
VCC2: C1.1, IC2.5 (VCC), Q1.2 (S), R2.2, S1.A (ANODE), S1.C (COLLECTOR)

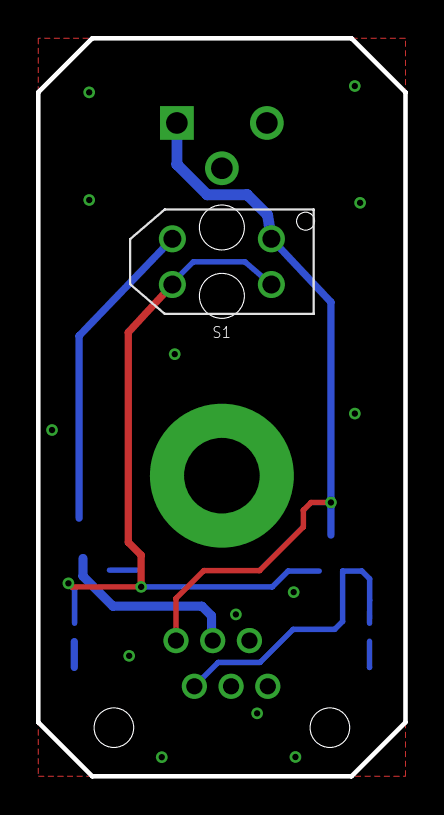
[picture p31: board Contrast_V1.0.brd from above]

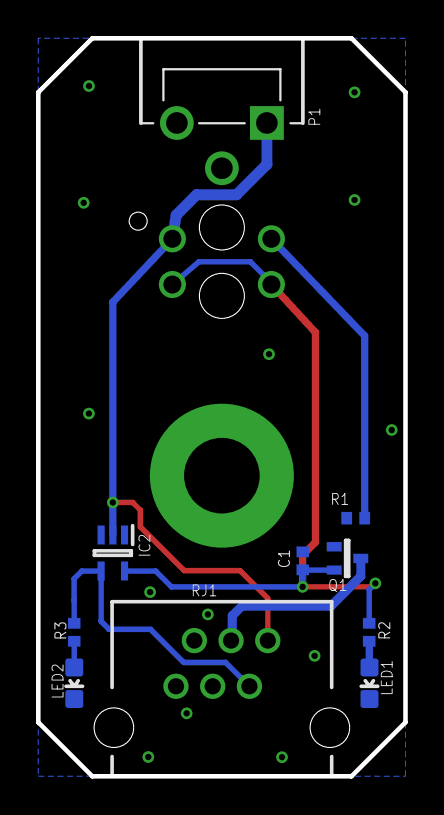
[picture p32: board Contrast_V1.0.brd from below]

Board: 2 copper layers, 20.4 x 41.0 mm, 11 parts (10 on the bottom side), 8 nets.

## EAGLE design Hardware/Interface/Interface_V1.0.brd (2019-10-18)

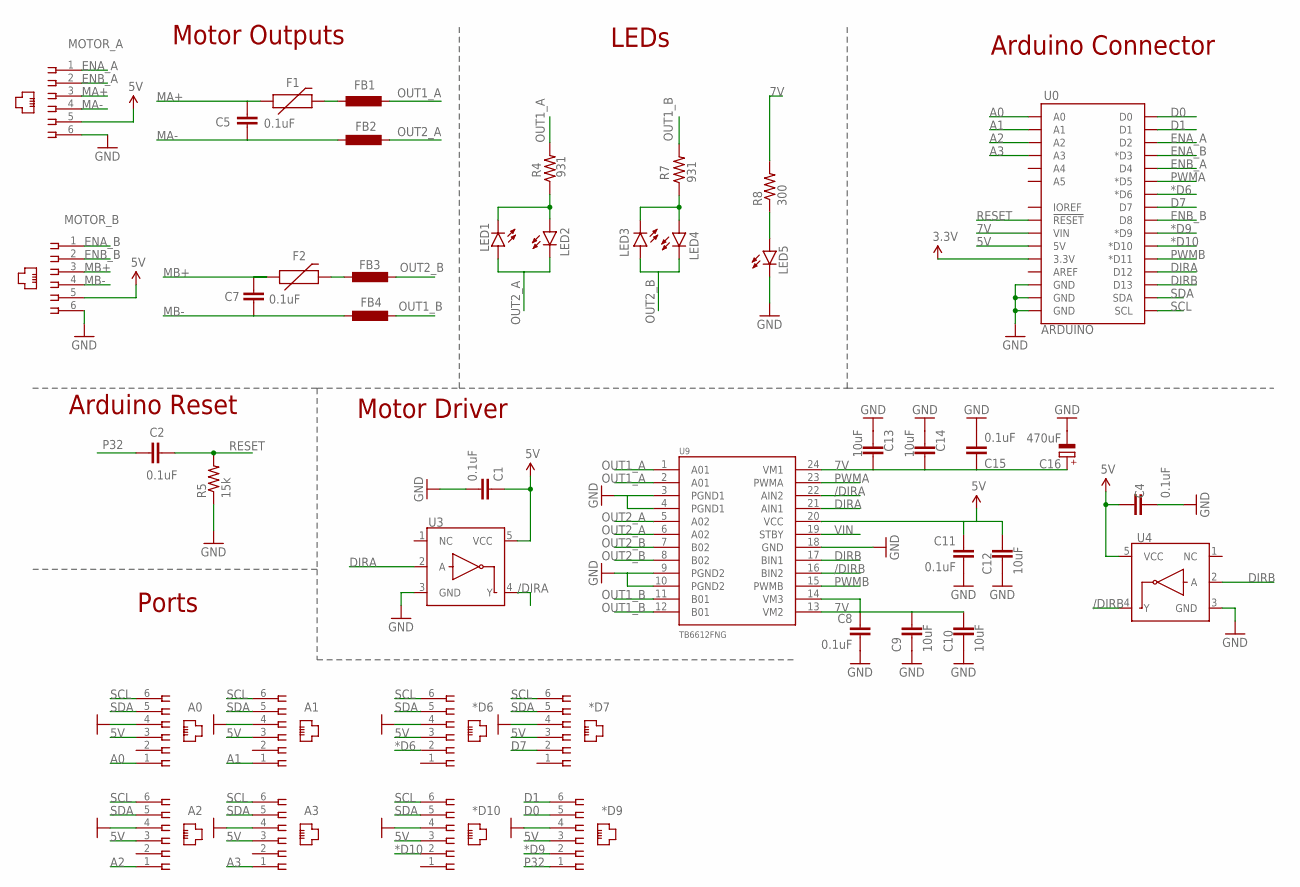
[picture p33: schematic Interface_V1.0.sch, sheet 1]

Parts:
*D6, *D7, *D9, *D10: 615006138421; MPNCH 623-PCB-6P6C
A0, A1, A2, A3: 615006138421; MPNCH 623-PCB-6P6C
C1, C2, C4, C5, C7, C8, C11, C15: 0.1uF; 0402; MPN CC0402KRX5R9BB104
C9, C10, C12, C13, C14: 10uF; C0603; MPN ZRB18AR61E106ME01L
C16: 470uF; PANASONIC_E; MPN EDH477M016A9MAA
F1, F2: PTC; PTC-1206; MPN 0ZCJ0100FF2E
FB1, FB2, FB3, FB4: FERRITE_BEAD; F0805; MPN 2508056017Y2
LED1, LED2, LED3, LED4: LED0603; LED-0603; MPN LTST-C193KRKT-5A
LED5: LED0603; LED-0603; MPN LW Q38G-Q2OO-3K5L-1
MOTOR_A: 615006138421; MPNCH 9901-6P6C
MOTOR_B: 615006138421; MPNCH 9901-6P6C
R4, R7: 931; RESC1005X35; MPN RC0402FR-07931RL
R5: 15k; RESC1005X35; MPN RC0402FR-0715KL
R8: 300; RESC1005X35; MPN RC0402JR-07300RL
U0: ARDUINO; ARDUINO_R3_NO_HOLES_SPI
U3, U4: INVERTER""; SC70; MPN 74AHC1G14GW-Q100,1
U9: TB6612FNG; SSOP24; MPN TB6612FNG,C,8,EL

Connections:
3.3V: U0.3.3V
5V: *D6.3, *D7.3, *D9.3, *D10.3, A0.3, A1.3, A2.3, A3.3, C1.1, C4.1, C11.1, C12.1, MOTOR_A.5, MOTOR_B.5, U0.5V, U3.5 (VCC), U4.5 (VCC), U9.20 (VCC)
7V: C8.1, C9.1, C10.1, C13.1, C14.1, C15.1, C16.+, R8.2, U0.VIN, U9.13 (VM2), U9.14 (VM3), U9.24 (VM1); also elsewhere on the board
*D6: *D6.2, U0.D6 (*D6)
*D9: *D9.2, U0.D9 (*D9)
*D10: *D10.2, U0.D10 (*D10)
/DIRA: U3.4 (Y), U9.22 (AIN2)
/DIRB: U4.4 (Y), U9.16 (BIN2)
A0: A0.1, U0.A0
A1: A1.1, U0.A1
A2: A2.1, U0.A2
A3: A3.1, U0.A3
D0: *D9.5, U0.D0
D1: *D9.6, U0.D1
D7: *D7.2, U0.D7
DIRA: U0.D12, U3.2 (A), U9.21 (AIN1)
DIRB: U0.D13, U4.2 (A), U9.17 (BIN1)
ENA_A: MOTOR_A.1, U0.D2
ENA_B: MOTOR_B.1, U0.D3 (*D3)
ENB_A: MOTOR_A.2, U0.D4
ENB_B: MOTOR_B.2, U0.D8
GND: *D6.4, *D7.4, *D9.4, *D10.4, A0.4, A1.4, A2.4, A3.4, C1.2, C4.2, C8.2, C9.2, C10.2, C11.2, C12.2, C13.2, C14.2, C15.2, C16.-, LED5.C, MOTOR_A.6, MOTOR_B.6, R5.1, U0.GND@1 (GND), U0.GND@2 (GND), U0.GND@3 (GND), U3.3 (GND), U4.3 (GND), U9.3 (PGND1), U9.4 (PGND1), U9.9 (PGND2), U9.10 (PGND2), U9.18 (GND); also elsewhere on the board
MA+: C5.1, F1.1, MOTOR_A.3
MA-: C5.2, FB2.1, MOTOR_A.4
MB+: C7.1, F2.1, MOTOR_B.3
MB-: C7.2, FB4.1, MOTOR_B.4
unnamed: LED1.C, LED2.A, R4.1
unnamed: LED3.C, LED4.A, R7.1
unnamed: F1.2, FB1.1
unnamed: F2.2, FB3.1
unnamed: LED5.A, R8.1
OUT1_A: FB1.2, R4.2, U9.1 (A01), U9.2 (A01)
OUT1_B: FB4.2, R7.2, U9.11 (B01), U9.12 (B01)
OUT2_A: FB2.2, LED1.A, LED2.C, U9.5 (A02), U9.6 (A02)
OUT2_B: FB3.2, LED3.A, LED4.C, U9.7 (B02), U9.8 (B02)
P32: *D9.1, C2.1
PWMA: U0.D5 (*D5), U9.23 (PWMA)
PWMB: U0.D11 (*D11), U9.15 (PWMB)
RESET: C2.2, R5.2, U0.RESET@1 (!RESET!)
SCL: *D6.6, *D7.6, *D10.6, A0.6, A1.6, A2.6, A3.6, U0.SCL
SDA: *D6.5, *D7.5, *D10.5, A0.5, A1.5, A2.5, A3.5, U0.SDA
VIN: U9.19 (STBY); also elsewhere on the board

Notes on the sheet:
Motor Outputs
LEDs
Arduino Connector
Motor Driver
Arduino Reset
Ports

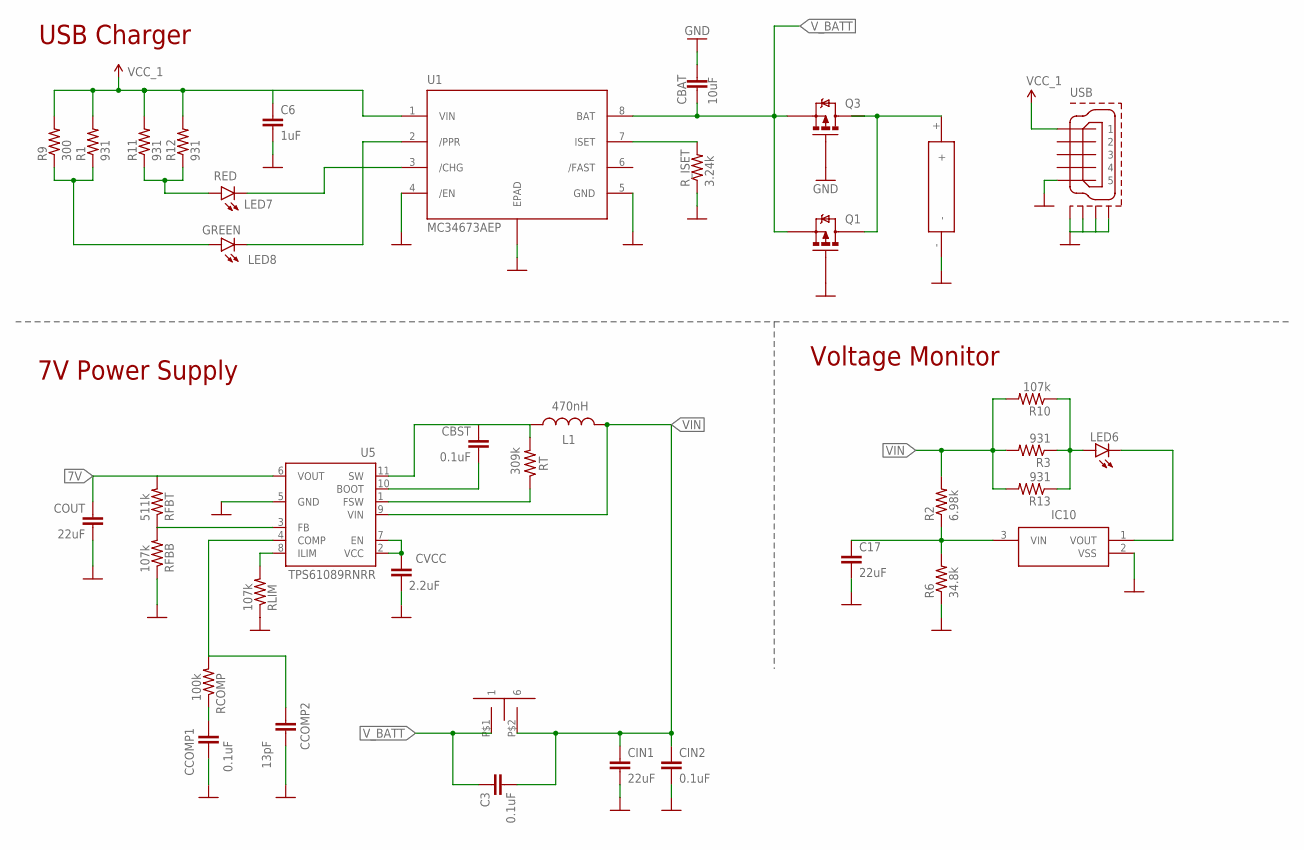
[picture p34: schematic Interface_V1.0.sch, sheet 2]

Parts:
B1: GPTS203212B; GPTS_RIGHT_ANGLE; MPN GPTS203212B
BATT: BATTERY; THM_HOLDER; MPN 1043
C3: 0.1uF; 0402; MPN CC0402KRX5R9BB104
C6: 1uF; 0402; MPN CC0402ZRY5V6BB105
C17: 22uF; C0603; MPN GRM188R61A226ME15D
CBAT: 10uF; C0603; MPN ZRB18AR61E106ME01L
CBST: 0.1uF; 0402; MPN CC0402KRX5R9BB104
CCOMP1: 0.1uF; 0402; MPN CC0402KRX5R9BB104
CCOMP2: 13pF; 0402; MPN CL05C130JB5NCNC
CIN1: 22uF; C0603; MPN GRM188R61A226ME15D
CIN2: 0.1uF; 0402; MPN CC0402KRX5R9BB104
COUT: 22uF; C1210; MPN GRM32ER61E226KE15L
CVCC: 2.2uF; C0603; MPN GRM188R61E225MA12D
IC10: TC54VN3002ECB713; SOT95P275X130-3N; MPN TC54VN3002ECB713
L1: 470nH; L2520; MPN DFE252012P-R47M=P2
LED6, LED7: LED0603; LED-0603; MPN LTST-C193KRKT-5A
LED8: LED0603; LED-0603; MPN LT Q39E-Q1OO-25-1
Q1: IRLML2244TRPBF; SOT95P237X112-3N; MANUFACTURER_PART_NUMBER IRLML2244TRPBF
Q3: IRLML2244TRPBF; SOT95P237X112-3N; MPN IRLML2244TRPBF
R1, R3, R11, R12, R13: 931; RESC1005X35; MPN RC0402FR-07931RL
R2: 6.98k; RESC1005X35; MPN RC0402FR-076K98L
R6: 34.8k; RESC1005X35; MPN RC0402FR-0734K8L
R9: 300; RESC1005X35; MPN RC0402JR-07300RL
R10: 107k; RESC1005X35; MPN RC0402FR-07107KL
RCOMP: 100k; RESC1005X35; MPN RC0402FR-07100KL
RFBB: 107k; RESC1005X35; MPN RC0402FR-07107KL
RFBT: 511k; RESC1005X35; MPN RC0402FR-07511KL
RLIM: 107k; RESC1005X35; MPN RC0402FR-07107KL
RT: 309k; RESC1005X35; MPN AC0402FR-07309KL
R_ISET: 3.24k; RESC1005X35; MPN RC0402FR-073K24L
U1: MC34673AEP; SOT1590-2; MPN MC34673AEPR2
U5: TPS61089RNRR; VQFN-11; MPN TPS61089RNRR
USB: MOLEX-47346-0001MOKO; A01SBXXXXXXX-470-MOKO; MPN 0473460001

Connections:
7V: COUT.1, RFBT.2, U5.6 (VOUT); also elsewhere on the board
GND: BATT.-, C6.2, C17.2, CBAT.1, CCOMP1.2, CCOMP2.2, CIN1.2, CIN2.2, COUT.2, CVCC.2, IC10.2 (VSS), Q1.1 (G), Q3.1 (G), R6.1, RFBB.1, RLIM.1, R_ISET.1, U1.4 (/EN), U1.5 (GND), U1.9 (EPAD), U5.5 (GND), USB.5, USB.GND1, USB.GND2, USB.GND3, USB.GND4, USB.GND5 (GND3), USB.GND6 (GND3); also elsewhere on the board
GREEN: LED8.C, U1.2 (/PPR)
unnamed: LED7.A, R11.1, R12.1
unnamed: LED8.A, R1.1, R9.1
unnamed: IC10.1 (VOUT), LED6.C
unnamed: C17.1, IC10.3 (VIN), R2.1, R6.2
unnamed: LED6.A, R3.1, R10.1, R13.1
unnamed: R_ISET.2, U1.7 (ISET)
unnamed: CVCC.1, U5.2 (VCC), U5.7 (EN)
unnamed: CBST.1, L1.2, RT.2, U5.11 (SW)
unnamed: RT.1, U5.1 (FSW)
unnamed: CBST.2, U5.10 (BOOT)
unnamed: RFBB.2, RFBT.1, U5.3 (FB)
unnamed: CCOMP2.1, RCOMP.2, U5.4 (COMP)
unnamed: CCOMP1.1, RCOMP.1
unnamed: RLIM.2, U5.8 (ILIM)
RED: LED7.C, U1.3 (/CHG)
VCC_1: C6.1, R1.2, R9.2, R11.2, R12.2, U1.1 (VIN), USB.1
VIN: B1.P$2 (6), C3.2, CIN1.1, CIN2.1, L1.1, R2.2, R3.2, R10.2, R13.2, U5.9 (VIN); also elsewhere on the board
V_B: BATT.+, Q1.3 (D), Q3.3 (D)
V_BATT: B1.P$1 (1), C3.1, CBAT.2, Q1.2 (S), Q3.2 (S), U1.8 (BAT)

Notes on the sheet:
RED
GREEN
USB Charger
7V Power Supply
Voltage Monitor

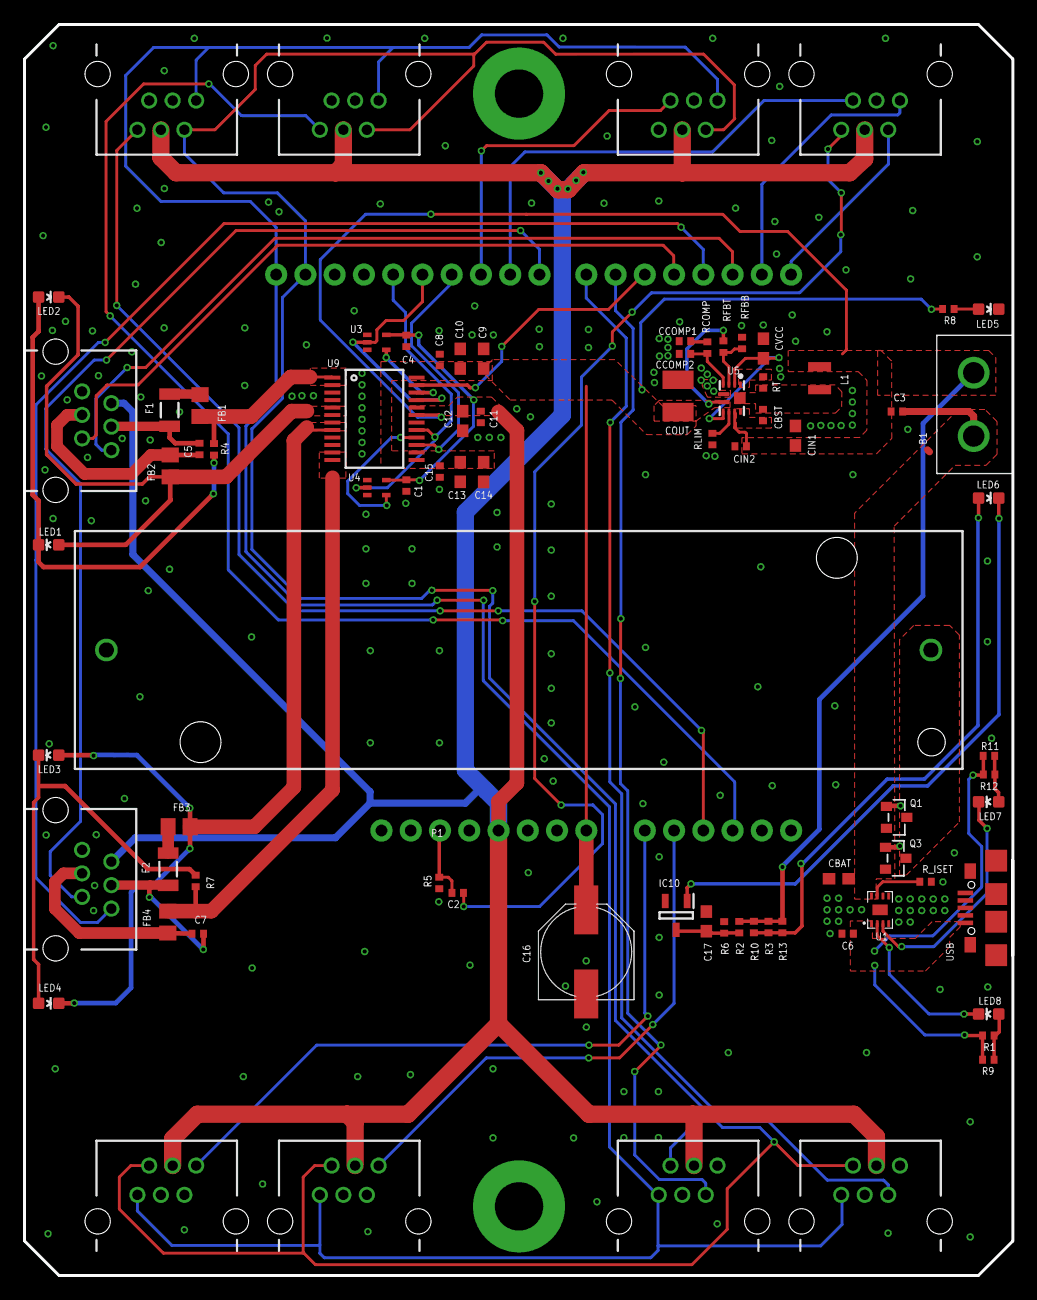
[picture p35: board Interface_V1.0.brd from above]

Board: 2 copper layers, 85.8 x 108.6 mm, 81 parts (0 on the bottom side), 60 nets.

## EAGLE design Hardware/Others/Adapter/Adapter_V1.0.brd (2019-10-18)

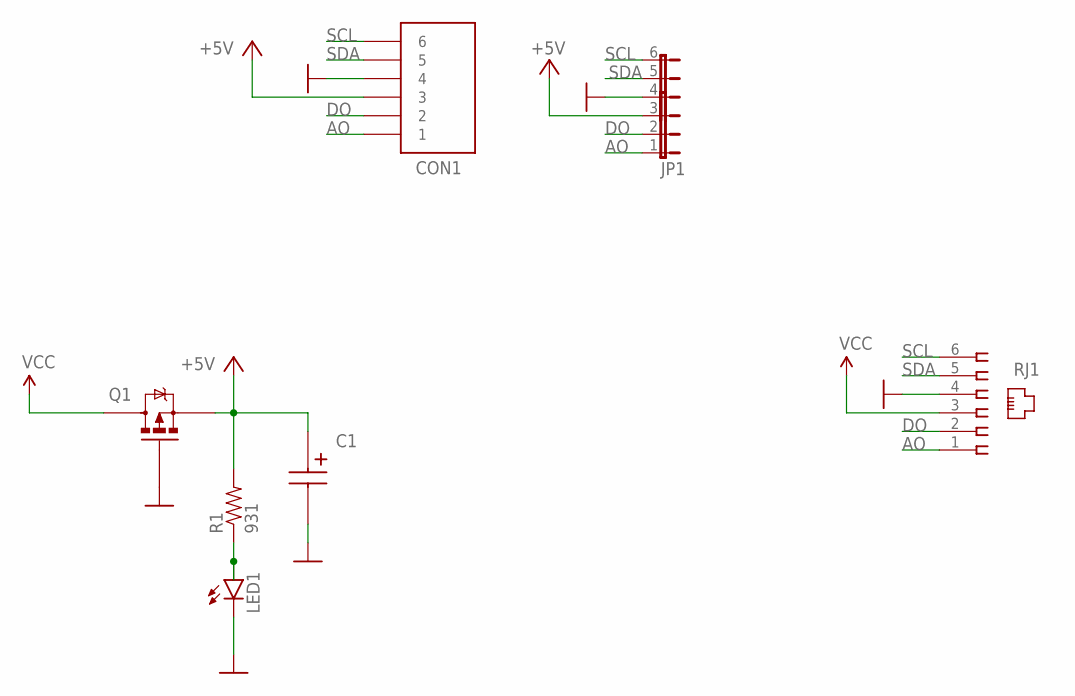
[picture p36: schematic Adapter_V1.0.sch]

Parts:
C1: 220uF; CAPPRD200W80D500H1100; MPN 227CKS010M
CON1: 1990041KF250A-2.5-6P; KF250A-2.5-6P; MPN 1990041
JP1: JP6E; JP6
LED1: LED0603; LED-0603; MPN LTST-C193KRKT-5A
Q1: IRLML2244TRPBF; SOT95P237X112-3N; MANUFACTURER_PART_NUMBER IRLML2244TRPBF
R1: 931; RESC1005X35; MPN RC0402FR-07931RL
RJ1: 615006138421; MPN 615006138421

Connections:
+5V: C1.1 (+), CON1.3, JP1.3, Q1.2 (S), R1.2
AO: CON1.1, JP1.1, RJ1.1
DO: CON1.2, JP1.2, RJ1.2
GND: C1.2 (-), CON1.4, JP1.4, LED1.C, Q1.1 (G), RJ1.4
unnamed: LED1.A, R1.1
SCL: CON1.6, JP1.6, RJ1.6
SDA: CON1.5, JP1.5, RJ1.5
VCC: Q1.3 (D), RJ1.3

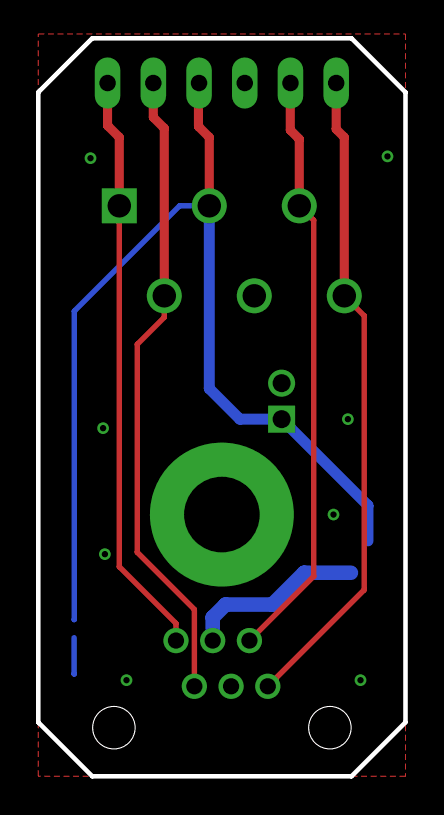
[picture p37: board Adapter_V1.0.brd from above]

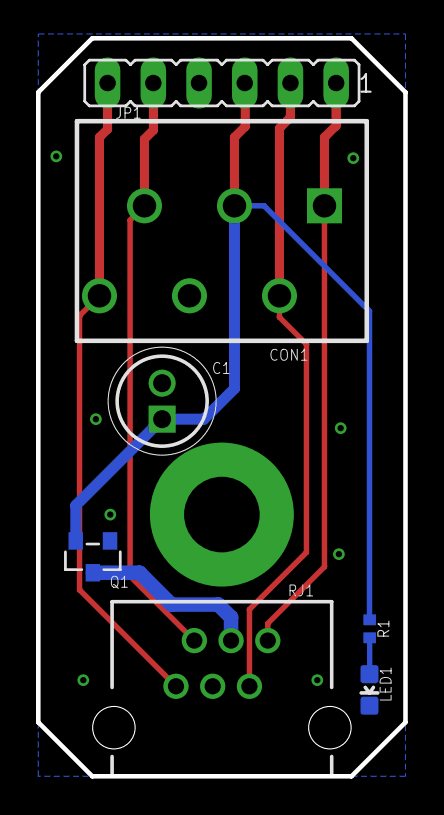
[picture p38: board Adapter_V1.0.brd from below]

Board: 2 copper layers, 20.4 x 41.0 mm, 7 parts (7 on the bottom side), 8 nets.

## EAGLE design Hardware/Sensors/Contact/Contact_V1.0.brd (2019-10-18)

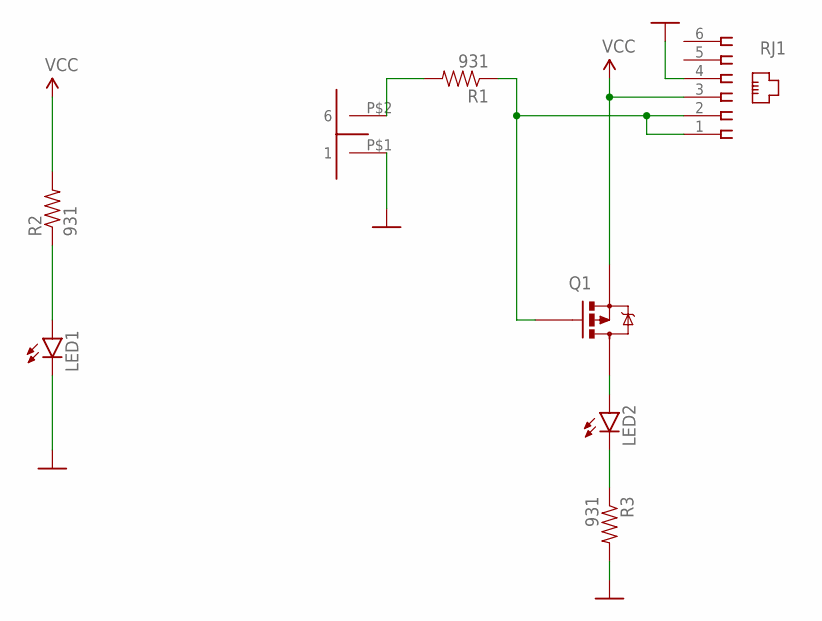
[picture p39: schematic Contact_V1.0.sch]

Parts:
LED1: LED0603; LED-0603; MPN LTST-C193KRKT-5A
LED2: LED0603; LED-0603; MPN LB Q39E-L2OO-35-1
PB1: PUSHBUTTON_MOKO; SUBSTITUTE_FSM104_RIGHT_ANGLE
Q1: RU1C002ZPTCL; SOTFL65P210X105-3N; MPN RU1C002ZPTCL
R1, R2, R3: 931; RESC1005X35; MPN RC0402FR-07931RL
RJ1: 615006138421; MPN 615006138421

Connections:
GND: LED1.C, PB1.P$1 (1), R3.2, RJ1.4
unnamed: PB1.P$2 (6), R1.2
unnamed: Q1.1 (G), R1.1, RJ1.1, RJ1.2
unnamed: LED2.A, Q1.3 (D)
unnamed: LED2.C, R3.1
unnamed: LED1.A, R2.1
VCC: Q1.2 (S), R2.2, RJ1.3

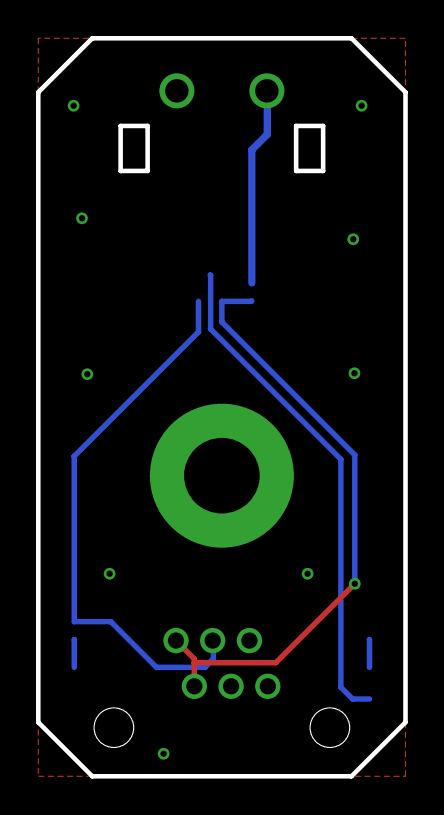
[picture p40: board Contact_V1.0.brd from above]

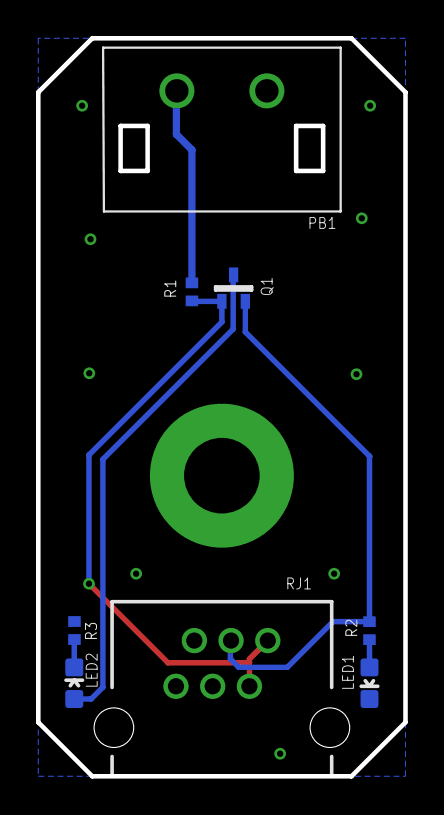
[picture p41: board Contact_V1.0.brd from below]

Board: 2 copper layers, 20.4 x 41.0 mm, 8 parts (8 on the bottom side), 7 nets.

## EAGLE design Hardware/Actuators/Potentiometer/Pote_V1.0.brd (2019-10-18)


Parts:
LED1: LED0603; LED-0603; MPN LTST-C193KRKT-5A
LED2: LED0603; LED-0603; MPN LB Q39E-L2OO-35-1
P1: 10k; PTV09A-2015F; MPN PTV09A-2025F-B103
Q1: RU1C002ZPTCL; SOTFL65P210X105-3N; MPN RU1C002ZPTCL
Q2: MMBT3904,215; SOT95P230X110-3N; MPN MMBT3904,215
R1, R2, R3, R4: 931; RESC1005X35; MPN RC0402FR-07931RL
RJ1: 615006138421; MPN 615006138421

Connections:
+5V: LED2.A, P1.3 (R_2), Q1.2 (S), R4.2
AO: P1.2 (WIPER), R1.2, RJ1.1
GND: LED1.C, P1.1 (R_1), Q1.1 (G), R2.2, R3.1, RJ1.4
unnamed: Q2.2 (E), R3.2
unnamed: LED2.C, Q2.3 (C)
unnamed: Q2.1 (B), R1.1, R2.1
unnamed: LED1.A, R4.1
VCC: Q1.3 (D), RJ1.3



Board: 2 copper layers, 20.4 x 41.0 mm, 10 parts (10 on the bottom side), 8 nets.

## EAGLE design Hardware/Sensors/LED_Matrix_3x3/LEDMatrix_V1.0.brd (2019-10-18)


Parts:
C1, C2, C3, C4, C5: 0.1uF; 0402; MPN CC0402KRX5R9BB104
LED1, LED2, LED3, LED4, LED5, LED6, LED7, LED8, LED9: SK6812MINI; MPN SK6812MINI
LED17: LED0603; LED-0603; MPN LTST-C193KRKT-5A
Q1: IRLML2244TRPBF; SOT95P237X112-3N; MANUFACTURER_PART_NUMBER IRLML2244TRPBF
R1: 300; RESC1005X35; MPN RC0402JR-07300RL
R2: 931; RESC1005X35; MPN RC0402FR-07931RL
RJ1: 615006138421; MPN 615006138421

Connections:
+5V: C1.1, C2.1, C3.1, C4.1, C5.1, LED1.2 (VDD), LED2.2 (VDD), LED3.2 (VDD), LED4.2 (VDD), LED5.2 (VDD), LED6.2 (VDD), LED7.2 (VDD), LED8.2 (VDD), LED9.2 (VDD), Q1.2 (S), R2.2
DI: LED1.1 (DI), R1.1
GND: C1.2, C2.2, C3.2, C4.2, C5.2, LED1.4 (GND), LED2.4 (GND), LED3.4 (GND), LED4.4 (GND), LED5.4 (GND), LED6.4 (GND), LED7.4 (GND), LED8.4 (GND), LED9.4 (GND), LED17.C, Q1.1 (G), RJ1.4
unnamed: LED1.3 (DO), LED2.1 (DI)
unnamed: LED2.3 (DO), LED3.1 (DI)
unnamed: LED3.3 (DO), LED4.1 (DI)
unnamed: LED5.3 (DO), LED6.1 (DI)
unnamed: LED17.A, R2.1
unnamed: LED4.3 (DO), LED5.1 (DI)
unnamed: LED6.3 (DO), LED7.1 (DI)
unnamed: LED7.3 (DO), LED8.1 (DI)
unnamed: LED8.3 (DO), LED9.1 (DI)
unnamed: R1.2, RJ1.1, RJ1.2
VCC: Q1.3 (D), RJ1.3


Board: 2 copper layers, 20.4 x 41.0 mm, 19 parts (1 on the bottom side), 14 nets.

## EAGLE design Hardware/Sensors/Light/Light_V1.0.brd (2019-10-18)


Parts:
C1, C2: 1uF; 0402; MPN CC0402ZRY5V6BB105
IC1: 74LVC1G14GW-Q100,1; SOT65P212X110-5N; MPN 74AHC1G14GW-Q100,1
LED1: LED0603; LED-0603; MPN LB Q39E-L2OO-35-1
LED2: LED0603; LED-0603; MPN LTST-C193KRKT-5A
P1: 100k; 3309W-1-104; MPN 3309W-1-104
Q1: RU1C002ZPTCL; SOTFL65P210X105-3N; MPN RU1C002ZPTCL
R1, R2: 931; RESC1005X35; MPN RC0402FR-07931RL
RJ1: 615006138421; MPN 54601-906WPLF
U1: NJL7302L-F3; MPN NJL7302L-F3

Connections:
AO: C2.1, IC1.2 (A), P1.1 (CCW), RJ1.1, U1.2 (E)
DO: IC1.4 (Y), R2.2, RJ1.2
GND: C1.2, C2.2, IC1.3 (GND), LED1.C, LED2.C, P1.2 (WIPER), Q1.1 (G), RJ1.4
unnamed: LED1.A, R2.1
unnamed: LED2.A, R1.1
VCC: Q1.3 (D), RJ1.3
VCC2: C1.1, IC1.5 (VCC), Q1.2 (S), R1.2, U1.1 (C)



Board: 2 copper layers, 20.4 x 41.0 mm, 11 parts (11 on the bottom side), 7 nets.

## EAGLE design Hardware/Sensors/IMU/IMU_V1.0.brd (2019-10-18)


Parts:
C1, C2, C3, C5: 0.1uF; 0402; MPN CC0402KRX5R9BB104
C4: 2200pF; 0402; MPN GRM155R71H222JA01D
C24, C26: 1uF; 0402; MPN CC0402ZRY5V6BB105
D2: BZT52C5V1-7-F; SOD3716X145N; MPN BZT52C5V1-7-F
IC1: MPU-6050; QFN50P400X400X95-25N; MPN MPU-6050
IC2: 74LVC1G14GW-Q100,1; SOT65P212X110-5N; MPN 74AHC1G14GW-Q100,1
IC3: MIC5504-3.3YM5-TR; SOT95P280X145-5N; MPN MIC5504-3.3YM5-TR
LED1: LED0603; LED-0603; MPN LTST-C193KRKT-5A
LED2: LED0603; LED-0603; MPN LB Q39E-L2OO-35-1
Q1: RU1C002ZPTCL; SOTFL65P210X105-3N; MPN RU1C002ZPTCL
Q2, Q3: RU1C002ZPTCL; SOTFL65P210X105-3N; MANUFACTURER_PART_NUMBER RU1C002ZPTCL
R1, R6, R7: 10k; RESC1005X35; MPN RC0402JR-7W10KL
R2, R3, R4: 931; RESC1005X35; MPN RC0402FR-07931RL
RJ1: 615006138421; MPN 615006138421
SJ1: SOLDERJUMPER_2WAYPASTE2&3; SJ_3_PASTE2&3

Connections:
3.3V: C2.1, C5.1, C26.1, IC1.8 (VLOGIC), IC1.13 (VDD), IC3.5 (VOUT), R6.2, R7.2, SJ1.1
GND: C1.2, C2.2, C3.2, C4.2, C5.2, C24.2, C26.2, D2.2 (A), IC1.18 (GND), IC1.25 (THERMAL_PAD), IC2.3 (GND), IC3.2 (GND), LED1.C, LED2.C, Q1.1 (G), R1.1, RJ1.4, SJ1.3
INT: IC1.12 (INT), RJ1.2
unnamed: Q1.2 (S), Q2.2 (S), Q3.2 (S), R4.2
unnamed: Q2.1 (G), Q3.3 (D), R1.2
unnamed: D2.1 (K), Q3.1 (G), R4.1
unnamed: IC2.4 (Y), R3.2
unnamed: LED2.A, R3.1
unnamed: C4.1, IC1.20 (CPOUT)
unnamed: C3.1, IC1.10 (REGOUT)
unnamed: IC1.9 (AD0), SJ1.2
unnamed: LED1.A, R2.1
SCL: IC1.23 (SCL), R6.1, RJ1.6
SDA: IC1.24 (SDA), IC2.2 (A), R7.1, RJ1.5
VCC: Q1.3 (D), RJ1.3
VCC2: C1.1, C24.1, IC2.5 (VCC), IC3.1 (VIN), IC3.3 (EN), Q2.3 (D), R2.2

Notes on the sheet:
I2C Address Selection*



Board: 2 copper layers, 20.4 x 41.0 mm, 24 parts (24 on the bottom side), 16 nets.

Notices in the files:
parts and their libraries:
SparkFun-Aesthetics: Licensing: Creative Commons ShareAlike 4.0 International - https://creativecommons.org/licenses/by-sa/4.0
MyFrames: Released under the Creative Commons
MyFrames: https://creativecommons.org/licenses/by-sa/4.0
